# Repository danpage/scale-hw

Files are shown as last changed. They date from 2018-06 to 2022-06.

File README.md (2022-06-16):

# [SCALE](http://www.github.com/danpage/scale): hardware-oriented material

<!--- -------------------------------------------------------------------- --->

## Concept

The equipment used for a typical 
[side-channel attack](http://en.wikipedia.org/wiki/Side-channel_attack)
based on
[power analysis](http://en.wikipedia.org/wiki/Power_analysis)
might resemble the following:

```
                                                                   .... +-------------+
                                                                  /     | SCALE       |
+-------------+         +-------------+   trigger  +-------------+      | target      |
| control     |   USB   | acquisition | <--------- | target      |      | board       |
| platform    | <-----> | platform    |   signal   | platform    |      +-------------+
|             |         |             | <--------- |             |      | SCALE       |
+-------------+         +-------------+            +-------------+      | host        |
      ^                                                  ^        \     | board       |   
      |           USB                                    |         .... +-------------+
      +--------------------------------------------------+
```

The basic idea is that

- the target      platform represents the device under attack,
  or the
  [Device Under Test (DUT)](http://en.wikipedia.org/wiki/Device_under_test)
  in more common terms,

- the acquisition platform represents a   device, e.g., an
  [oscilloscope](http://en.wikipedia.org/wiki/Oscilloscope),
  to capture a signal from the target platform (under control of a trigger)
  and relay it to the control platform,

- the control     platform represents a workstation, which orchestrates the 
  attack by controlling the target and acquisition platforms: it will often
  repeat an acquisition loop, i.e.,

  - configure (e.g., fix the acquisition period) and initialise (e.g., arm 
    the trigger) the acquisition platform,
  - send    input     (e.g.,  plaintext) to   target      platform,
  - invoke  operation (e.g., encryption) on   target      platform,
  - receive output    (e.g., ciphertext) from target      platform,
    then,
  - receive trace                        from acquisition platform,

  to acquire a set of traces, then apply some 
  [(crypt)analytic](http://en.wikipedia.org/wiki/Cryptanalysis) 
  technique to them in order to recover information.

None of the above is an unreasonable expectation within the context of a 
research-oriented lab. but may present challenges in a teaching-oriented
alternative.  For example, particularly at scale, it may be that

- the 
  [Total Cost of Ownership (TCO)](http://en.wikipedia.org/wiki/Total_cost_of_ownership),
  i.e., capital investment plus maintenance, 
- the domain-specific requirements on 
  [Commercial Off-The-Shelf (COTS)](http://en.wikipedia.org/wiki/Commercial_off-the-shelf)
  target boards, such as the need to insert a shunt resistor into the 
  power rail,
- the need to expose at least some
  [EE](http://en.wikipedia.org/wiki/Electrical_engineering)-style 
  detail to students without a suitable background,

prevent such an approach being viable (or make it less effective).

This repo. captures a suite of 
bespoke, hardware-based target platform designs:
when combined with suitable control and acquisition platforms, it offers
a real, albeit sanitised "kit" for learning about side-channel attacks.
It has a strict remit, namely educational use (e.g., as a lab. exercise 
or assignment), which to some extent determines goals, design decisions, 
and, ultimately, the content.

<!--- -------------------------------------------------------------------- --->

## Quickstart

- Install any pre-requisites, e.g., support for
  [Git Large File Storage (LFS)](http://git-lfs.github.com/)
  (without this, some content will appear as a set of pointers to data vs. the data itself).

- Clone the repo.

  ```sh
  git clone https://github.com/danpage/scale-hw.git ./scale-hw
  cd ./scale-hw
  git submodule update --init --recursive
  source ./bin/conf.sh
  ```

- Create and populate a suitable Python
  [virtual environment](https://docs.python.org/3/library/venv.html)
  based on 
  [`${REPO_HOME}/requirements.txt`](./requirements.txt) 
  by executing
   
  ```sh
  make venv
  ```
   
  then activate it by executing
   
  ```sh
  source ${REPO_HOME}/build/venv/bin/activate
  ``` 

- Select a target board, e.g., by setting the environment variable

  ```sh
  export TARGET="lpc1313fbd48"
  ```

- Build the material 
  by executing

  ```sh
  make --directory="${REPO_HOME}/src/scale/target/${TARGET}" build
  ```

- Make use of the material in

  ```sh
  ${REPO_HOME}/build/${TARGET}
  ```

  e.g.,

  - build   the example:

    ```sh
    make --directory="${REPO_HOME}/src/scale/example" --file="${REPO_HOME}/build/${TARGET}/lib/scale.mk" PROJECT="example" BSP="${REPO_HOME}/build/${TARGET}" USB="/dev/ttyUSB0" build
    ```

  - program the example (i.e., execute it on physical hardware):

    ```sh
    make --directory="${REPO_HOME}/src/scale/example" --file="${REPO_HOME}/build/${TARGET}/lib/scale.mk" PROJECT="example" BSP="${REPO_HOME}/build/${TARGET}" USB="/dev/ttyUSB0" program
    ```

  - emulate the example (i.e., execute it on  virtual hardware):

    ```sh
    make --directory="${REPO_HOME}/src/scale/example" --file="${REPO_HOME}/build/${TARGET}/lib/scale.mk" PROJECT="example" BSP="${REPO_HOME}/build/${TARGET}" USB="/dev/ttyUSB0" emulate
    ```

<!--- -------------------------------------------------------------------- --->

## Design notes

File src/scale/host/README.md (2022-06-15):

# [SCALE](http://www.github.com/danpage/scale): hardware-oriented material (host board)

<!--- -------------------------------------------------------------------- --->

## Hardware 

Revision | Prototype                                                                                                 | PCB                                                                                           | Design files                                                                                                                                                                                                                 |
:------: | :-------------------------------------------------------------------------------------------------------: | :-------------------------------------------------------------------------------------------: | :--------------------------------------------------------------------------------------------------------------------------------------------------------------------------------------------------------------------------: |
C.1      |  |  | [schematic](./board.sch) (plus [PDF](./board.pdf)), [board](./board.brd), [BOM](./board.csv), [OSH Park (PCB)](http://www.oshpark.com/shared_projects/F13RPtpf), [Octopart (BOM)](http://www.octopart.com/bom-tool/LBFQutEU) |

- All communication with a control platform is performed via a
  [USB](http://en.wikipedia.org/wiki/USB)-to-[UART](http://en.wikipedia.org/wiki/Universal_asynchronous_receiver/transmitter)
  bridge, namely an
  [FTDI FT232RL](http://www.ftdichip.com/Support/Documents/DataSheets/ICs/DS_FT232R.pdf)
  (which ultimately connects to `DUT_RXD` and `DUT_TXD`).
  The surrounding design

  - basically matches the
    [SparkFun FTDI Basic Breakout](http://cdn.sparkfun.com/datasheets/BreakoutBoards/FTDI%20Basic-v22-3.3V.pdf),
    but includes a polyfuse (the breadboard prototype seems to pull about
    30 mA @ 3.3V),

  - differs from Figure 7.4 (page 31) of FT232RL datasheet wrt. both the 
    capacitors, and lack of ferrite bead.

- Both `DUT_RST` and `DUT_GPI` are connected to
  [SPST switches](http://en.wikipedia.org/wiki/Switch)
  switches.
  The surrounding design is motivated by 
  [Arduino UNO](http://www.arduino.cc/en/uploads/Main/arduino-uno-schematic.pdf),
  replacing `GND` with `UART_DTR` on the non-switch side of the capacitor
  to allow a programmer, e.g., `avrdude`, to perform a "remote reset".

- The center pin of `H.J2` ultimately supplies power the target board via 
  `DUT_VCC`: a jumper can be used to select between

  - a   5 V supply stemming from the FT232RL,
    or
  - a 3.3 V supply stemming from the FT232RL,

  or, by default (i.e., with no jumper), an external power supply which
  is provided via the labelled SMA connector and hence `PSU`.

- A signal is acquired from either `DUT_VCC` or `DUT_SIGI`, depending on
  `H.J4`, before being processed by a pipeline of components and produced
  via `DUT_SIGO`.

  - The pipeline includes a 
    100 ohm shunt resistor,
    which can be enabled or disabled using `H.J3`.

  - The pipeline includes a
    [Low Noise Amplifier (LNA)](http://en.wikipedia.org/wiki/Low-noise_amplifier),
    namely an
    [NXP BGA2801](http://www.nxp.com/documents/data_sheet/BGA2801.pdf),
    which can be enabled or disabled using `H.J5`.
    The surrounding design is basically the same as the
    [ChipWhisperer LNA module](http://wiki.newae.com/CW502_Low_Noise_Amplifier),
    which, in turn, is basically the same as the NXP reference design in
    Figure 1 (page 4) of the BGA2801 datasheet.
  
  - The pipeline includes a
    [low-pass filter](http://en.wikipedia.org/wiki/Low-pass_filter);
    which can be enabled or disabled using `H.J6`.
    The surrounding design is based in a "pi-section" structure, i.e.,
  
    ```
                 L
      ----o---8888888---o----
          |             |
          = C/2         = C/2
          |             |
         GND           GND
    ```
  
    where we select
    L   =  10.0 uH
    and
    C/2 =   1.5 nF
    to produce roughly a 2.6 MHz cut-off.

- `DUT_SCL` and `DUT_SDA` are connected to three
  [Atmel CryptoAuthentication](http://www.atmel.com/products/security-ics/cryptoauthentication)
  I2C peripherals, 
  which can be enabled or disabled using `H.J7`.
  More specifically, those peripherals are one each of

  - [ATAES132A](http://www.atmel.com/Images/Atmel-8914-CryptoAuth-ATAES132A-Datasheet.pdf),
  - [ATSHA204A](http://www.atmel.com/images/Atmel-8885-CryptoAuth-ATSHA204A-Datasheet.pdf),
    and
  - [ATECC508A](http://www.atmel.com/Images/Atmel-8923S-CryptoAuth-ATECC508A-Datasheet-Summary.pdf),

  that offer hardware-backed, cryptography-related functionality and
  some amount of generic 
  [EEPROM](http://en.wikipedia.org/wiki/EEPROM)
  storage.

<!--- -------------------------------------------------------------------- --->

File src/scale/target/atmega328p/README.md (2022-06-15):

# [SCALE](http://www.github.com/danpage/scale): hardware-oriented material (target board: atmega328p)

<!--- -------------------------------------------------------------------- --->

## Hardware 

Revision | Prototype                                                                                                 | PCB                                                                                           | Design files                                                                                                                                                                                                                 |
:------: | :-------------------------------------------------------------------------------------------------------: | :-------------------------------------------------------------------------------------------: | :--------------------------------------------------------------------------------------------------------------------------------------------------------------------------------------------------------------------------: |
C.1      |  |  | [schematic](./board.sch) (plus [PDF](./board.pdf)), [board](./board.brd), [BOM](./board.csv), [OSH Park (PCB)](http://www.oshpark.com/shared_projects/YczSc1Wc), [Octopart (BOM)](http://www.octopart.com/bom-tool/CbDjCRPB) |

- The target board houses an 
  8-bit Atmel ATmega
  core, which acts as the 
  [DUT](http://en.wikipedia.org/wiki/Device_under_test).
  More specifically, the DUT is a
  28-pin, DIP-format
  [Atmel atmega328p](http://www.atmel.com/Images/Atmel-42735-8-bit-AVR-Microcontroller-ATmega328-328P_Datasheet.pdf)
  IC; 
  it has 32 kB FLASH and 2 kB SRAM memory.

- Relevant aspects of the DUT pin-out, and their relationship with the
  target board schematic, are illustrated below:

  ```
                       +------------+
  DUT_RST   = PC6  =  1|            |28 =         DUT_SCL
  DUT_RXD   = PD0  =  2|            |27 =         DUT_SDA
  DUT_TXD   = PD1  =  3|            |26
  DUT_GPI   = PD2  =  4|            |25
                      5|            |24
                      6|            |23
  DUT_VCC   = VCC  =  7| ATmega328p |22 =  GND
              GND  =  8|            |21
  DUT_XTAL1 = PB6  =  9|            |20 =  VCC  = DUT_VCC
  DUT_XTAL2 = PB7  = 10|            |19 =  SCK
                     11|            |18 =  MISO
                     12|            |17 =  MOSI
  DUT_GPO   = PD7  = 13|            |16
  DUT_TGR   = PB0  = 14|            |15
                       +------------+
  ```

- The core voltage required on `DUT_VCC` is 5 V: 
  `H.J2` must therefore be set appropriately.

- The core has a
  1 MHz
  internal clock source, but can be driven by either 

  - an external clock source provided (on `DUT_XTAL1` and `DUT_XTAL2` via `DUT_CLK`),
    or
  - 16 MHz external crystal housed on the target board.

  To support these, some extra, carefully selected capacitors
  are required: the DUT
  [datasheet](http://www.atmel.com/Images/Atmel-42735-8-bit-AVR-Microcontroller-ATmega328-328P_Datasheet.pdf)
  specifies that

  | Type    | Reference   | XTALIN  (`DUT_XTAL1`)                                  | XTALOUT (`DUT_XTAL2`)   |
  |:-------:|:-----------:|:------------------------------------------------------:|:-----------------------:|
  | Crystal | Figure 13-2 | C1   =  22 pF = 0.022 nF                               | C2   = 22 pF = 0.022 nF |
  | Clock   | Figure 13-3 | no capacitors required                                 | disconnected            |

- Specific pins on the DUT are made accessible via `T.J2` in order to
  allow attachment of a hardware programmer or debugger.
  For example, it is possible to attach an
  [Atmel AVRISP mkII](http://www.atmel.com/Images/Atmel-42093-AVR-ISP-mkII_UserGuide.pdf)
  (or indeed *any* low-cost ISP-based programmer)
  to the DUT by connecting the 6-pin header as follows

  ```
             +-----+
     MISO = 1|     |2 = DUT_VCC
      SCK = 3| ISP |4 = MOSI
  DUT_RST = 5|     |6 = DUT_GND
             +-----+
  ```

  taking care wrt. pin 2.  Some programmers will sense a core voltage
  from this pin, some will *supply* a core voltage using it, some can
  be configured to do either: by whatever means (e.g., disconnecting
  the pin, or configuring the programmer), do *not* use it supply a 
  core voltage.

<!--- -------------------------------------------------------------------- --->

## Software

- Under
  [Ubuntu](http://www.ubuntu.com)-based
  Linux, for example, 
  the development dependencies can be installed 
  by issuing the command

  ```
  sudo apt-get install gcc-avr avrdude
  ```

- We assume an Arduino-based
  [bootloader](http://en.wikipedia.org/wiki/Booting),
  such as
  [Optiboot](http://www.github.com/Optiboot/optiboot),
  has been pre-installed to allow programming of the DUT over USB;
  this means
  [avrdude](http://www.nongnu.org/avrdude)
  can be used as is,
  as can the Arduino
  [IDE](http://www.arduino.cc/en/main/software)
  if you prefer.

- Note that the default BSP configuration is conservative, st.

  - the
    external 16 MHz crystal
    is used as the clock source,
    meaning `T.J3` and `T.J4` on the target board 
    must be set appropriately,
  - the 
    UART 
    interface operates per 9600/8N1,
  - the
    I2C
    interface operates per 100 kHz standard mode.

<!--- -------------------------------------------------------------------- --->

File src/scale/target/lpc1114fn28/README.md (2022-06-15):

# [SCALE](http://www.github.com/danpage/scale): hardware-oriented material (target board: lpc1114fn28)

<!--- -------------------------------------------------------------------- --->

## Hardware 

Revision | Prototype                                                                                                 | PCB                                                                                           | Design files                                                                                                                                                                                                                 |
:------: | :-------------------------------------------------------------------------------------------------------: | :-------------------------------------------------------------------------------------------: | :--------------------------------------------------------------------------------------------------------------------------------------------------------------------------------------------------------------------------: |
C.1      |  |  | [schematic](./board.sch) (plus [PDF](./board.pdf)), [board](./board.brd), [BOM](./board.csv), [OSH Park (PCB)](http://www.oshpark.com/shared_projects/XgebkWyr), [Octopart (BOM)](http://www.octopart.com/bom-tool/vM74sniH) |

- The target board houses a
  32-bit ARM Cortex-M0 
  core, which acts as the 
  [DUT](http://en.wikipedia.org/wiki/Device_under_test).
  More specifically, the DUT is a
  28-pin, DIP-format
  [NXP lpc114fn28/102](http://www.nxp.com/documents/data_sheet/LPC111X.pdf)
  IC (the
  [user manual](http://www.nxp.com/documents/user_manual/UM10398.pdf)
  for which is more detailed); 
  it has 32 kB FLASH and 4 kB SRAM memory.
  Unfortunately NXP have discontinued this part, although you can often
  still source instances via
  [ebay](http://www.ebay.co.uk/sch/lpc114fn28).

- Relevant aspects of the DUT pin-out, and their relationship with the
  target board schematic, are illustrated below:

  ```
                       +----------------+
  DUT_TRG = PIO0_8 =  1|                |28
  DUT_GPO = PIO0_9 =  2|                |27           = DUT_SCL            
            SWCLK  =  3|                |26             
                      4|                |25             
  DUT_SDA =           5|                |24 = PIO0_1  = DUT_GPI
                      6|                |23           = DUT_RST       
                      7| lpc114fn28/102 |22 = GND     = DUT_GND
                      8|                |21 = VCC     = DUT_VCC
                      9|                |20 = XTALIN  = DUT_XTAL1
                     10|                |19 = XTALOUT = DUT_XTAL2
                     11|                |18             
            SWDIO  = 12|                |17             
                     13|                |16           = DUT_TXD       
                     14|                |15           = DUT_RXD
                       +----------------+
  ```

- The core voltage required on `DUT_VCC` is 3.3 V: 
  `H.J2` must therefore be set appropriately.

- The core has a
  12 MHz
  internal oscillator, but can be driven by either 

  - an external clock source provided (on `DUT_XTAL1` and `DUT_XTAL2` via `DUT_CLK`),
    or
  - 16 MHz external crystal housed on the target board.

  To support these, some extra, carefully selected capacitors
  are required: the DUT
  [datasheet](http://www.nxp.com/documents/data_sheet/LPC111X.pdf)
  specifies that for C_L = 10 pF crystal load capacitance,

  | Type    | Reference             | XTALIN  (`DUT_XTAL1`)                                  | XTALOUT (`DUT_XTAL2`)   |
  |:-------:|:---------------------:|:------------------------------------------------------:|:-----------------------:|
  | Crystal | Figure 50, Table  30  | C_X1 =  18 pF = 0.018 nF                               | C_X2 = 18 pF = 0.018 nF |
  | Clock   | Figure 49             | C_i  = 100 pF = 0.100 nF <br/> C_g = 300 pF = 0.300 nF | disconnected            |

  In the latter case we want 200 mV < f * V_RMS < 1000 mV, where
  f = C_i / ( C_i + C_g ),
  so if we pick V_peak = 3.3 V, then because
  V_RMS  = V_peak * \sqrt{duty cycle}
         = 3.3    * \sqrt{1/2}
        ~= 2.3
  then f = 1/4 and hence C_g = 300 pF does the job.

- Specific pins on the DUT are made accessible via `T.J2` in order to
  allow attachment of a hardware programmer or debugger.
  For example, it is possible to attach a
  [Segger J-Link](http://www.segger.com/admin/uploads/productDocs/UM08001_JLink.pdf)
  to the DUT by connecting the 20-pin header as follows

  ```
              +--------+
  DUT_VCC =  1|        |2
             3|        |4  = DUT_GND
             5|        |6
    SWDIO =  7|        |8
    SWCLK =  9| J-Link |10
            11|        |12
            13|        |14
  DUT_RST = 15|        |16
            17|        |18
            19|        |20
              +--------+
  ```
               
  and thereby make use of Serial Wire Debug (SWD).

<!--- -------------------------------------------------------------------- --->

## Software

- Under
  [Ubuntu](http://www.ubuntu.com)-based
  Linux, for example, 
  the development dependencies can be installed 
  by issuing the command

  ```
  sudo apt-get install gcc-arm-none-eabi lpc21isp
  ```

  That said, some versions of this 
  [Ubuntu packaged](https://launchpad.net/ubuntu/+source/gcc-arm-none-eabi) 
  tool-chain have known issues 
  (see, e.g., [1](https://bugs.launchpad.net/gcc-arm-embedded/+bug/1722849)
              or
              [2](https://bugs.launchpad.net/gcc-arm-embedded/+bug/1502611));
  take care, or, as an alternative, consider using an 
  ["official" release](https://developer.arm.com/tools-and-software/open-source-software/developer-tools/gnu-toolchain)
  directly from ARM instead.

- A pre-installed 
  [bootloader](http://en.wikipedia.org/wiki/Booting)
  allows programming of the DUT over USB;
  this means
  [lpc21isp](http://sourceforge.net/projects/lpc21isp)
  can be used as is.  
  The GPI switch on the host board will activate the bootloader during 
  reset, so the steps required are basically

  - execute lpc2isp, which then waits,
  - press and hold the (right-hand) GPI   switch,  
  - press and hold the  (left-hand) reset switch,
  - release        the  (left-hand) reset switch,
  - transfer via lpc2isp starts,
  - release        the (right-hand) GPI   switch,
  - transfer via lpc2isp finishes.

- Note that the default BSP configuration is conservative, st.

  - the
    internal 12 MHz oscillator
    is used as the clock source,
    meaning `T.J3` and `T.J4` on the target board 
    are irrelevant,
  - the 
    UART 
    interface operates per 9600/8N1,
  - the
    I2C
    interface operates per 100 kHz standard mode.

<!--- -------------------------------------------------------------------- --->

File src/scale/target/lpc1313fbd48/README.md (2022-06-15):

# [SCALE](http://www.github.com/danpage/scale): hardware-oriented material (target board: lpc1313fbd48)

<!--- -------------------------------------------------------------------- --->

## Hardware 

Revision | Prototype                                                                                                 | PCB                                                                                           | Design files                                                                                                                                                                                                                 |
:------: | :-------------------------------------------------------------------------------------------------------: | :-------------------------------------------------------------------------------------------: | :--------------------------------------------------------------------------------------------------------------------------------------------------------------------------------------------------------------------------: |
C.1      |  |  | [schematic](./board.sch) (plus [PDF](./board.pdf)), [board](./board.brd), [BOM](./board.csv), [OSH Park (PCB)](http://www.oshpark.com/shared_projects/dp9i0DIr), [Octopart (BOM)](http://www.octopart.com/bom-tool/5ZnEZk9y) |

- The target board houses a
  32-bit ARM Cortex-M3
  core, which acts as the 
  [DUT](http://en.wikipedia.org/wiki/Device_under_test).
  More specifically, the DUT is a
  48-pin, LQFP-format
  [NXP lpc1313fbd48/151](http://www.nxp.com/docs/en/data-sheet/LPC1311_13_42_43.pdf)
  IC (the
  [user manual](http://www.nxp.com/docs/en/user-guide/UM10375.pdf)
  for which is more detailed); 
  it has 32 kB FLASH and 8 kB SRAM memory.

- Relevant aspects of the DUT pin-out, and their relationship with the
  target board schematic, are illustrated below:

  ```
                             +----------------------- = TXD    = DUT_TXD
                             | +--------------------- = RXD    = DUT_RXD
                             | |   +----------------- = VDD    = DUT_VCC
                             | |   |     +----------- = VSS    = DUT_GND
                             | |   |     |   +------- = SWDIO
                             | |   |     |   |
                                           
                           4 4 4 4 4 4 4 4 4 3 3 3
                           8 7 6 5 4 3 2 1 0 9 8 7
                          +-----------------------+
                         1|                       |36
                         2|                       |35 
  DUT_RST             =  3|                       |34 = PIO1_1 = DUT_GPO
  DUT_GPI   = PIO0_1  =  4|                       |33 = PIO1_0 = DUT_TRG
  DUT_GND   = VSS     =  5|                       |32
  DUT_XTAL1 = XTALIN  =  6|      lpc1313fbd48     |31
  DUT_XTAL2 = XTALOUT =  7|                       |30
  DUT_VCC   = VDD     =  8|                       |29 = SWCLK
                         9|                       |28 = SWO
                        10|                       |27
                        11|                       |26
                        12|                       |25
                          +-----------------------+
                           1 1 1 1 1 1 1 2 2 2 2 2
                           3 4 5 6 7 8 9 0 1 2 3 4

                               | |
  DUT_SCL   = SCL     = -------+ |
  DUT_SDA   = SDA     = ---------+
  ```

- The core voltage required on `DUT_VCC` is 3.3 V: 
  `H.J2` must therefore be set appropriately.

- The core has a
  12 MHz
  internal oscillator, but can be driven by either 

  - an external clock source provided (on `DUT_XTAL1` and `DUT_XTAL2` via `DUT_CLK`),
    or
  - 16 MHz external crystal housed on the target board.

  To support these, some extra, carefully selected capacitors
  are required: the DUT
  [datasheet](http://www.nxp.com/docs/en/data-sheet/LPC1311_13_42_43.pdf)
  specifies that for C_L = 10 pF crystal load capacitance,

  | Type    | Reference             | XTALIN  (`DUT_XTAL1`)                                  | XTALOUT (`DUT_XTAL2`)   |
  |:-------:|:---------------------:|:------------------------------------------------------:|:-----------------------:|
  | Crystal | Figure 35, Table  21  | C_X1 =  18 pF = 0.018 nF                               | C_X2 = 18 pF = 0.018 nF |
  | Clock   | Figure 34             | C_i  = 100 pF = 0.100 nF <br/> C_g = 300 pF = 0.300 nF | disconnected            |

  In the latter case we want 200 mV < f * V_RMS < 1000 mV, where
  f = C_i / ( C_i + C_g ),
  so if we pick V_peak = 3.3 V, then because
  V_RMS  = V_peak * \sqrt{duty cycle}
         = 3.3    * \sqrt{1/2}
        ~= 2.3
  then f = 1/4 and hence C_g = 300 pF does the job.

- Specific pins on the DUT are made accessible via `T.J2` in order to
  allow attachment of a hardware programmer or debugger.
  For example, it is possible to attach a
  [Segger J-Link](http://www.segger.com/admin/uploads/productDocs/UM08001_JLink.pdf)
  to the DUT by connecting the 20-pin header as follows

  ```
              +--------+
  DUT_VCC =  1|        |2
             3|        |4  = DUT_GND
             5|        |6
    SWDIO =  7|        |8
    SWCLK =  9| J-Link |10
            11|        |12
            13|        |14
  DUT_RST = 15|        |16
            17|        |18
            19|        |20
              +--------+
  ```
               
  and thereby make use of Serial Wire Debug (SWD).

  That said, it *seems* the DUT isn't correctly identified by 
  [OpenOCD](http://openocd.org),
  at least per version 
  [0.10.0](http://sourceforge.net/p/openocd/code/ci/v0.10.0/tree/).  
  It's not totally clear why: the flash driver seems to read a part ID
  of `0x2000002B` (vs. an expected part ID `0x2C40102B`).  This can be 
  resolved by adding something like

  ```
  #define LPC1313_2 0x2000002B
  ```
 
  plus an appropriate case in the `lpc2000_auto_probe_flash` function 
  of
  [`${OPENOCD}/src/flash/nor/lpc2000.c`](http://sourceforge.net/p/openocd/code/ci/v0.10.0/tree/src/flash/nor/lpc2000.c);
  alternatively, apply the
  [patch](./openocd-0.10.0.patch)
  provided.

<!--- -------------------------------------------------------------------- --->

## Software

- Under
  [Ubuntu](http://www.ubuntu.com)-based
  Linux, for example, 
  the development dependencies can be installed 
  by issuing the command

  ```
  sudo apt-get install gcc-arm-none-eabi lpc21isp
  ```

  That said, some versions of this 
  [Ubuntu packaged](https://launchpad.net/ubuntu/+source/gcc-arm-none-eabi) 
  tool-chain have known issues 
  (see, e.g., [1](https://bugs.launchpad.net/gcc-arm-embedded/+bug/1722849)
              or
              [2](https://bugs.launchpad.net/gcc-arm-embedded/+bug/1502611)):
  take care, or, as an alternative, consider using an 
  ["official" release](https://developer.arm.com/tools-and-software/open-source-software/developer-tools/gnu-toolchain)
  directly from ARM instead.

- A pre-installed 
  [bootloader](http://en.wikipedia.org/wiki/Booting)
  allows programming of the DUT over USB;
  this means
  [lpc21isp](http://sourceforge.net/projects/lpc21isp)
  can be used as is.  
  The GPI switch on the host board will activate the bootloader during 
  reset, so the steps required are basically

  - execute lpc2isp, which then waits,
  - press and hold the (right-hand) GPI   switch,  
  - press and hold the  (left-hand) reset switch,
  - release        the  (left-hand) reset switch,
  - transfer via lpc2isp starts,
  - release        the (right-hand) GPI   switch,
  - transfer via lpc2isp finishes.

- Note that the default BSP configuration is conservative, st.

  - the
    internal 12 MHz oscillator
    is used as the clock source,
    meaning `T.J3` and `T.J4` on the target board 
    are irrelevant,
  - the 
    UART 
    interface operates per 9600/8N1,
  - the
    I2C
    interface operates per 100 kHz standard mode.

<!--- -------------------------------------------------------------------- --->

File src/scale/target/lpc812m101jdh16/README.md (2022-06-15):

# [SCALE](http://www.github.com/danpage/scale): hardware-oriented material (target board: lpc812m101jdh16)

<!--- -------------------------------------------------------------------- --->

## Hardware 

Revision | Prototype                                                                                                 | PCB                                                                                           | Design files                                                                                                                                                                                                                 |
:------: | :-------------------------------------------------------------------------------------------------------: | :-------------------------------------------------------------------------------------------: | :--------------------------------------------------------------------------------------------------------------------------------------------------------------------------------------------------------------------------: |
C.1      |  |  | [schematic](./board.sch) (plus [PDF](./board.pdf)), [board](./board.brd), [BOM](./board.csv), [OSH Park (PCB)](http://www.oshpark.com/shared_projects/ANKAjSGc), [Octopart (BOM)](http://www.octopart.com/bom-tool/BlsVKS9M) |

- The target board houses a
  32-bit ARM Cortex-M0+
  core, which acts as the 
  [DUT](http://en.wikipedia.org/wiki/Device_under_test).
  More specifically, the DUT is a
  16-pin, TSSOP-format
  [NXP lpc812m101jdh16](http://www.nxp.com/documents/data_sheet/LPC81XM.pdf)
  IC (the
  [user manual](http://www.nxp.com/documents/user_manual/UM10601.pdf)
  for which is more detailed); 
  it has 16 kB FLASH and 4 kB SRAM memory.

- Relevant aspects of the DUT pin-out, and their relationship with the
  target board schematic, are illustrated below:

  ```
                        +-----------------+
                       1|                 |16 = PIO0_0  = DUT_RXD
  DUT_GPI = PIO0_12 =  2|                 |15 = PIO0_6  = DUT_TRG
  DUT_RST =            3|                 |14 = PIO_7   = DUT_GPO
  DUT_TXD = PIO0_4  =  4| lpc812m101jdh16 |13 = GND     = DUT_GND
            SWCLK   =  5|                 |12 = VCC     = DUT_VCC
            SWDIO   =  6|                 |11 = XTALIN  = DUT_XTAL1
  DUT_SCL =            7|                 |10 = XTALOUT = DUT_XTAL2
  DUT_SDA =            8|                 |9 
                        +-----------------+
  ```

- The core voltage required on `DUT_VCC` is 3.3 V: 
  `H.J2` must therefore be set appropriately.

- The core has a
  12 MHz
  internal oscillator, but can be driven by either 

  - an external clock source provided (on `DUT_XTAL1` and `DUT_XTAL2` via `DUT_CLK`),
    or
  - 16 MHz external crystal housed on the target board.

  To support these, some extra, carefully selected capacitors
  are required: the DUT
  [datasheet](http://www.nxp.com/documents/data_sheet/LPC81XM.pdf)
  specifies that for C_L = 10 pF crystal load capacitance,

  | Type    | Reference             | XTALIN  (`DUT_XTAL1`)                                  | XTALOUT (`DUT_XTAL2`)   |
  |:-------:|:---------------------:|:------------------------------------------------------:|:-----------------------:|
  | Crystal | Figure 37, Table  26  | C_X1 =  18 pF = 0.018 nF                               | C_X2 = 18 pF = 0.018 nF |
  | Clock   | Figure 36             | C_i  = 100 pF = 0.100 nF <br/> C_g = 300 pF = 0.300 nF | disconnected            |

  In the latter case we want 200 mV < f * V_RMS < 1000 mV, where
  f = C_i / ( C_i + C_g ),
  so if we pick V_peak = 3.3 V, then because
  V_RMS  = V_peak * \sqrt{duty cycle}
         = 3.3    * \sqrt{1/2}
        ~= 2.3
  then f = 1/4 and hence C_g = 300 pF does the job.

- Specific pins on the DUT are made accessible via `T.J2` in order to
  allow attachment of a hardware programmer or debugger.
  For example, it is possible to attach a
  [Segger J-Link](http://www.segger.com/admin/uploads/productDocs/UM08001_JLink.pdf)
  to the DUT by connecting the 20-pin header as follows

  ```
              +--------+
  DUT_VCC =  1|        |2
             3|        |4  = DUT_GND
             5|        |6
    SWDIO =  7|        |8
    SWCLK =  9| J-Link |10
            11|        |12
            13|        |14
  DUT_RST = 15|        |16
            17|        |18
            19|        |20
              +--------+
  ```
               
  and thereby make use of Serial Wire Debug (SWD).

<!--- -------------------------------------------------------------------- --->

## Software

- Under
  [Ubuntu](http://www.ubuntu.com)-based
  Linux, for example, 
  the development dependencies can be installed 
  by issuing the command

  ```
  sudo apt-get install gcc-arm-none-eabi lpc21isp
  ```

  That said, some versions of this 
  [Ubuntu packaged](https://launchpad.net/ubuntu/+source/gcc-arm-none-eabi) 
  tool-chain have known issues 
  (see, e.g., [1](https://bugs.launchpad.net/gcc-arm-embedded/+bug/1722849)
              or
              [2](https://bugs.launchpad.net/gcc-arm-embedded/+bug/1502611));
  take care, or, as an alternative, consider using an 
  ["official" release](https://developer.arm.com/tools-and-software/open-source-software/developer-tools/gnu-toolchain)
  directly from ARM instead.

- A pre-installed 
  [bootloader](http://en.wikipedia.org/wiki/Booting)
  allows programming of the DUT over USB;
  this means
  [lpc21isp](http://sourceforge.net/projects/lpc21isp)
  can be used as is.  
  The GPI switch on the host board will activate the bootloader during 
  reset, so the steps required are basically

  - execute lpc2isp, which then waits,
  - press and hold the (right-hand) GPI   switch,  
  - press and hold the  (left-hand) reset switch,
  - release        the  (left-hand) reset switch,
  - transfer via lpc2isp starts,
  - release        the (right-hand) GPI   switch,
  - transfer via lpc2isp finishes.

- Note that the default BSP configuration is conservative, st.

  - the
    internal 12 MHz oscillator
    is used as the clock source,
    meaning `T.J3` and `T.J4` on the target board 
    are irrelevant,
  - the 
    UART 
    interface operates per 9600/8N1,
  - the
    I2C
    interface operates per 100 kHz standard mode.

<!--- -------------------------------------------------------------------- --->

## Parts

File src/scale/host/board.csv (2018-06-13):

Qty | Line Item | Manufacturer | Schematic Reference | Description
1 | FT232RL | FTDI | H.UART | USB to UART bridge; SSOP-28
1 | BGA2801,115 | NXP Semiconductors | H.AMP | wideband amplifier; SOT-363
1 | ATAES132A-SHER-B | Microchip | H.I2C1 | crypto. co-processor; SOIC-8
1 | ATSHA204A-SSHDA-B | Microchip | H.I2C2 | crypto. co-processor; SOIC-8
1 | ATECC108A-SSHDA-B | Microchip | H.I2C3 | crypto. co-processor; SOIC-8
2 | B3F-4000 | Omron | H.S1, H.S2 | SPST switch
1 | 61729-1011BLF | FCI | H.USB | USB receptacle
1 | 5-146281-2 | TE Connectivity | H.J7 | 2x1 male header
5 | 5-146281-3 | TE Connectivity | H.J2, H.J3, H.J4, H.J5, H.J6 | 3x1 male header
2 | 929974-01-16 | 3M | H.J1L, H.J1R | 16x1 female header
5 | 5-1814400-1 | TE Connectivity | H.X1, H.X2, H.X3, H.X4, H.X5 | horizontal female SMA connector
2 | APT3216SGC | Kingbright | H.D1, H.D2 | green LED; 1206
2 | APT3216YC | Kingbright | H.D3, H.D4 | yellow LED; 1206
1 | APT3216EC | Kingbright | H.D5 | red LED; 1206
1 | 1206L025YR | Littelfuse | H.F1 | 500 mA polyfuse; 1206
1 | MLZ1608N100LT000 | TDK | H.L1 | 10 uH inductor; 0603
1 | T491A106K010AT | KEMET | H.C3 | 10 uF tantalum capacitor; 1206
2 | C0603C152J8RACTU | KEMET | H.C10, H.C11 | 1.5 nF = 1500 pF ceramic capacitor; 0603
1 | C0603C223K1RACTU | KEMET | H.C8 | 22 nF = 0.022 uF ceramic capacitor; 0603
6 | C0603C104K8RACTU | KEMET | H.C1, H.C2, H.C4, H.C5, H.C6, H.C9 | 100 nF = 0.1 uF ceramic capacitor; 0603
1 | C0603C475K8PACTU | KEMET | H.C7 | 4.7 uF ceramic capacitor; 0603
1 | CR0603-JW-101ELF | Bourns | H.R8 | 100 ohm resistor; 0603
5 | CR0603-JW-102ELF | Bourns | H.R1, H.R2, H.R3, H.R4, H.R5 | 1k ohm resistor; 0603
2 | CR0603-JW-103ELF | Bourns | H.R6, H.R7 | 10k ohm resistor; 0603
2 | CR0603-JW-392ELF | Bourns | H.R9, H.R10 | 3.9k ohm resistor; 0603

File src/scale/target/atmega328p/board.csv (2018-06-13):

Qty | Line Item | Manufacturer | Schematic Reference | Description
1 | FOXSLF/160-20 | Fox Electronics | T.XTAL | 16 MHz crystal
1 | 952-2748-ND | Harwin | T.DUT | 28-pin DIP socket
1 | ATMEGA328P-PU | Microchip | T.DUT; DIP-28
2 | 5-146281-2 | TE Connectivity | T.J5, T.J6 | 2x1 male header
2 | 5-146281-3 | TE Connectivity | T.J3, T.J4 | 3x1 male header
1 | 5-146254-3 | TE Connectivity | T.J2 | 3x2 male header
2 | 961116-6404-AR | 3M | T.J1L, T.J1R | 16x1 male header
2 | C0603C220J5GACTU | KEMET | T.C1, T.C2 | 0.022 nF = 22 pF ceramic capacitor; 0603

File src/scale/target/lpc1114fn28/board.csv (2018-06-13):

Qty | Line Item | Manufacturer | Schematic Reference | Description
1 | FOXSLF/160-20 | Fox Electronics | T.XTAL | 16 MHz crystal
1 | 9-1437539-2 | TE Connectivity | T.DUT | 28-pin DIP socket
1 | LPC1114FN28/102,12 | NXP Semiconductors | T.DUT; DIP-28
2 | 5-146281-2 | TE Connectivity | T.J5, T.J6 | 2x1 male header
2 | 5-146281-3 | TE Connectivity | T.J3, T.J4 | 3x1 male header
1 | 4-103328-4 | TE Connectivity | T.J2 | 10x2 male header
2 | 961116-6404-AR | 3M | T.J1L, T.J1R | 16x1 male header
2 | C0603C180J5GACTU | KEMET | T.C1, T.C2 | 0.018 nF = 18 pF ceramic capacitor; 0603
1 | C0603C301J5GACTU | KEMET | T.C3 | 0.3 nF = 300 pF ceramic capacitor; 0603
1 | C0603C101J5GACTU | KEMET | T.C4 | 0.1 nF = 100 pF ceramic capacitor; 0603

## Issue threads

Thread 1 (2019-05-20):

lpc81x / M0+ builds not working - Typo in lpc81x.S

ben-marshall, 2019-05-20:
[Line 22](https://github.com/danpage/scale-hw/blob/fa15667bf32cdae6ed65c8f2c26735290ff85429/share/lpc81x/lpc81x.S#L22) of `/share/lpc81x/lpc81x.S` makes the wrong symbol name globally available.

It currently says `LPC81X_GPIO0`, but should say `LPC81X_GPIO` - i.e., there shouldn't be a trailing zero.

danpage, 2019-05-20:
Great: thanks.  I'm collecting a bunch of fixes in the `fixes` branch, so have addressed it there and will merge into `master` once I'm done with the rest.

Closed 2019-05-31.

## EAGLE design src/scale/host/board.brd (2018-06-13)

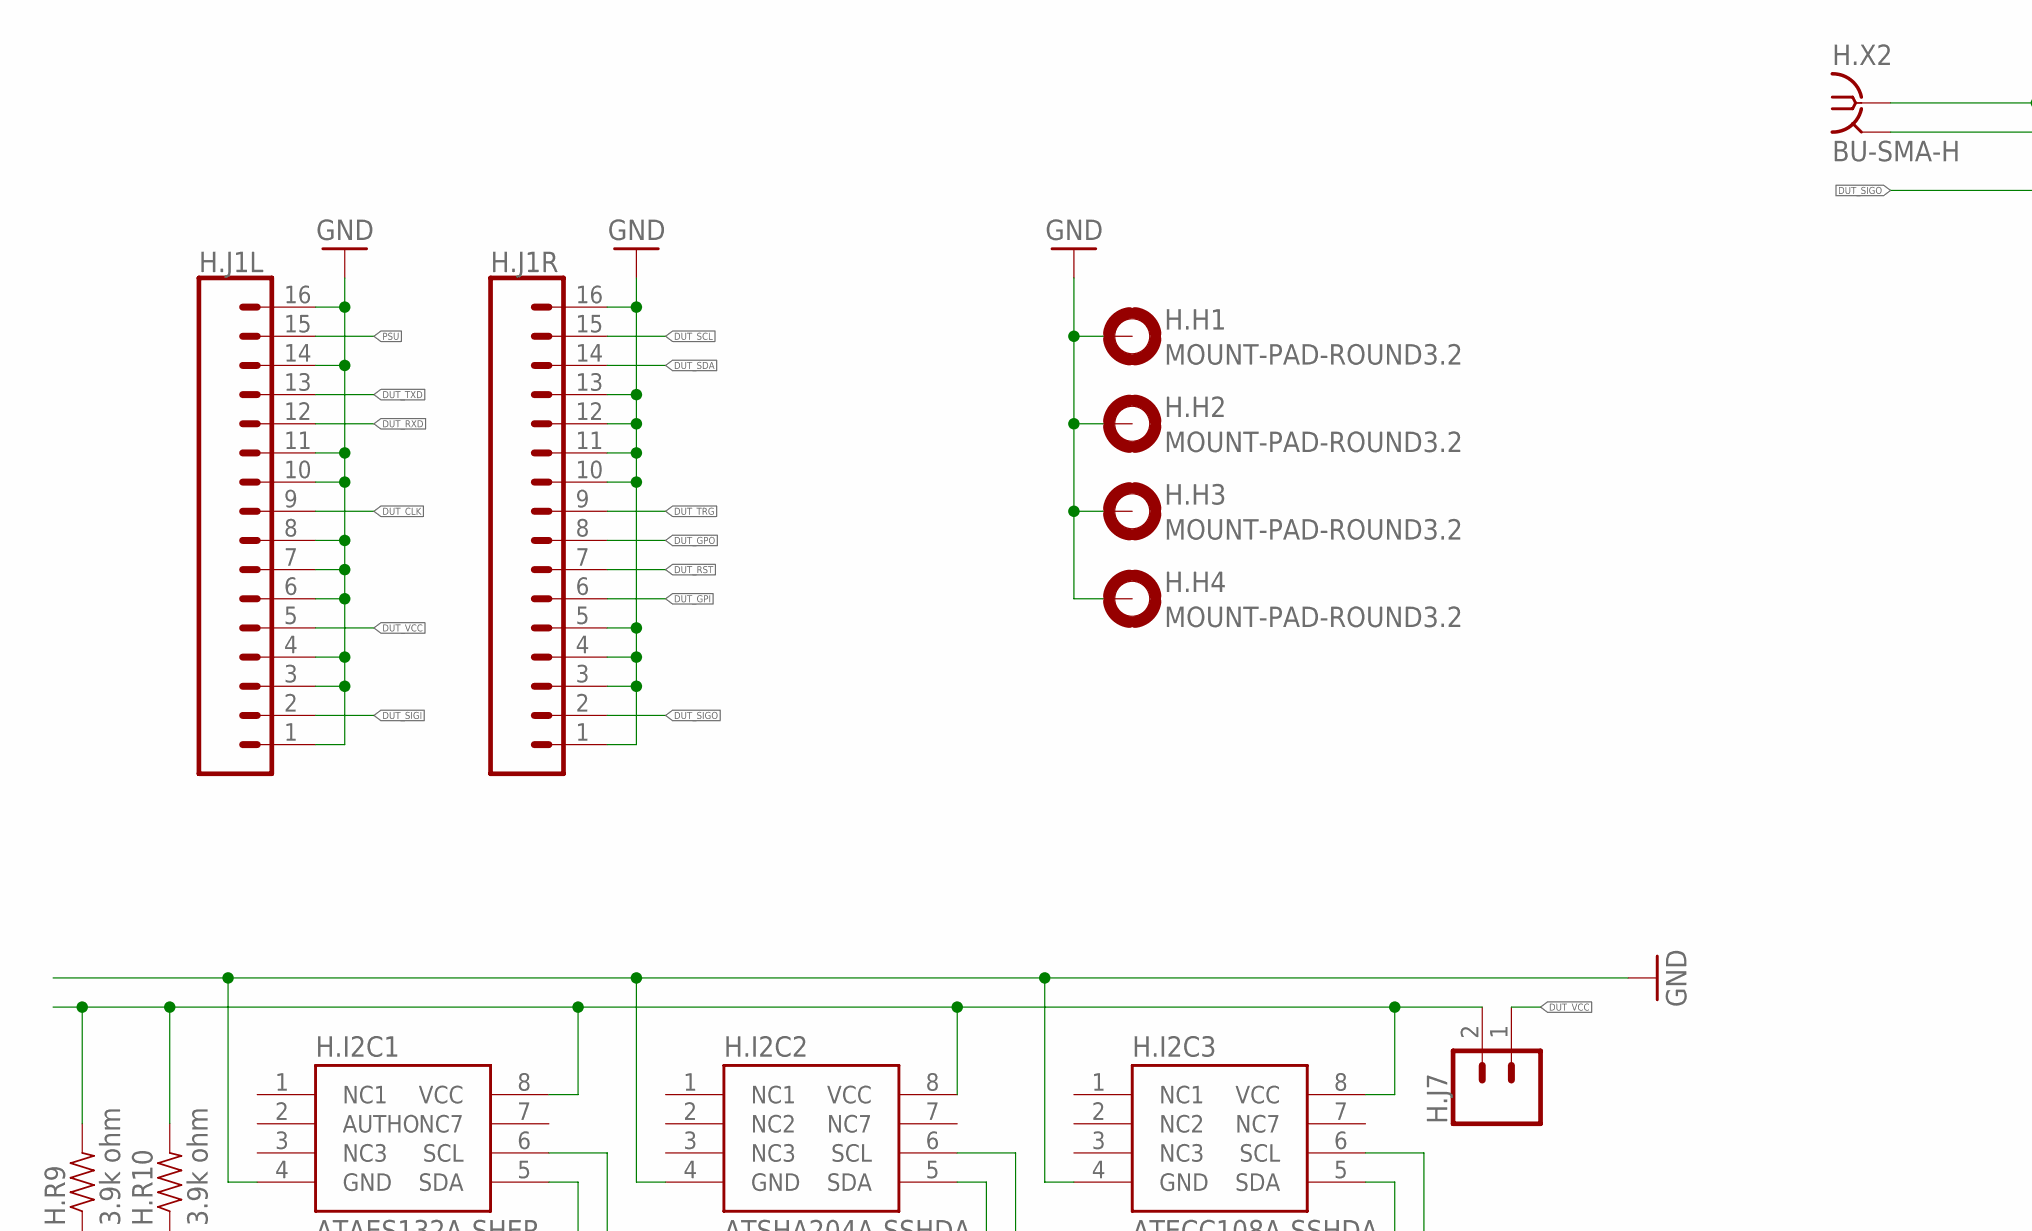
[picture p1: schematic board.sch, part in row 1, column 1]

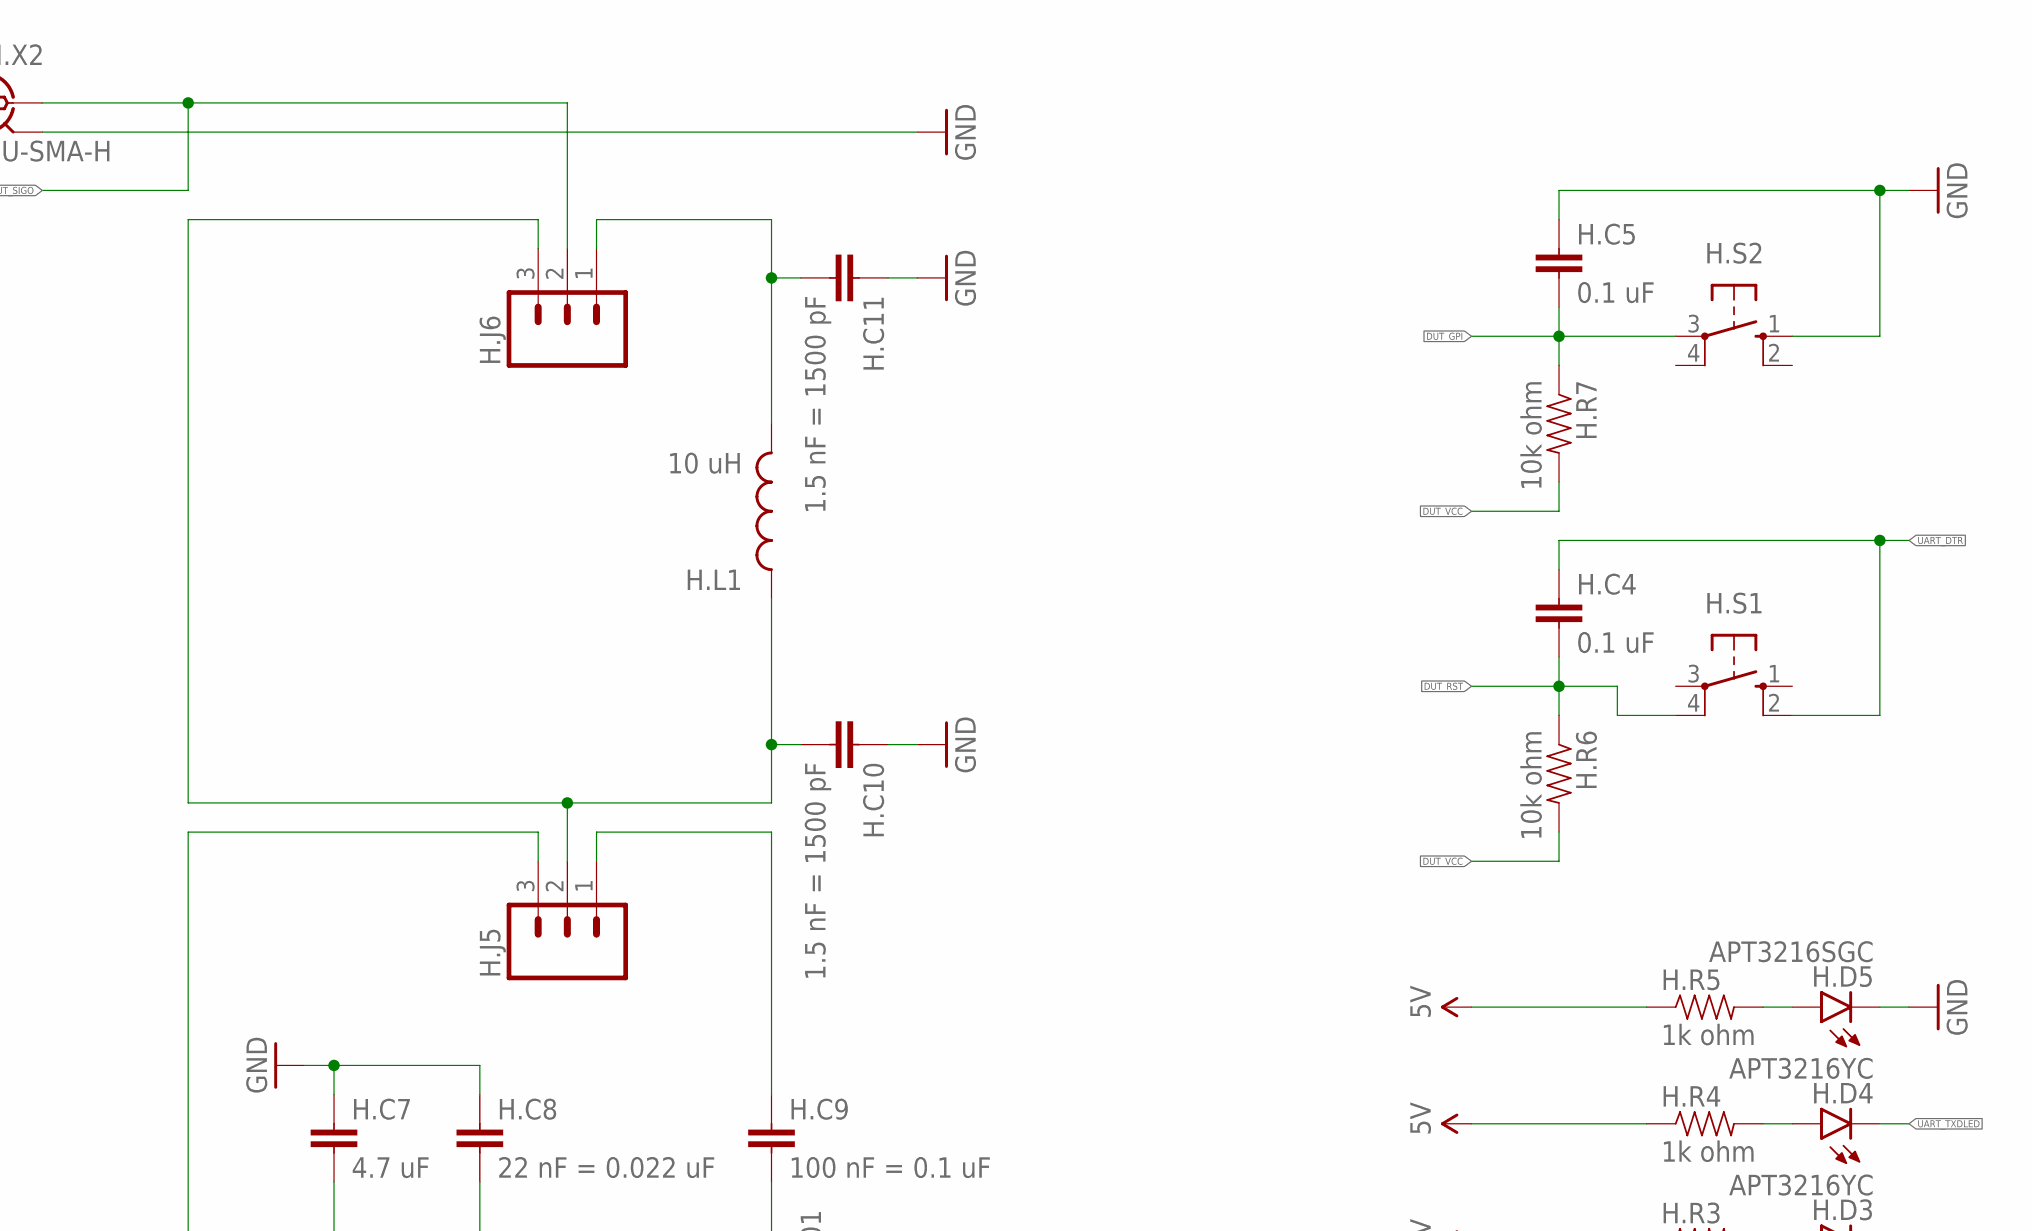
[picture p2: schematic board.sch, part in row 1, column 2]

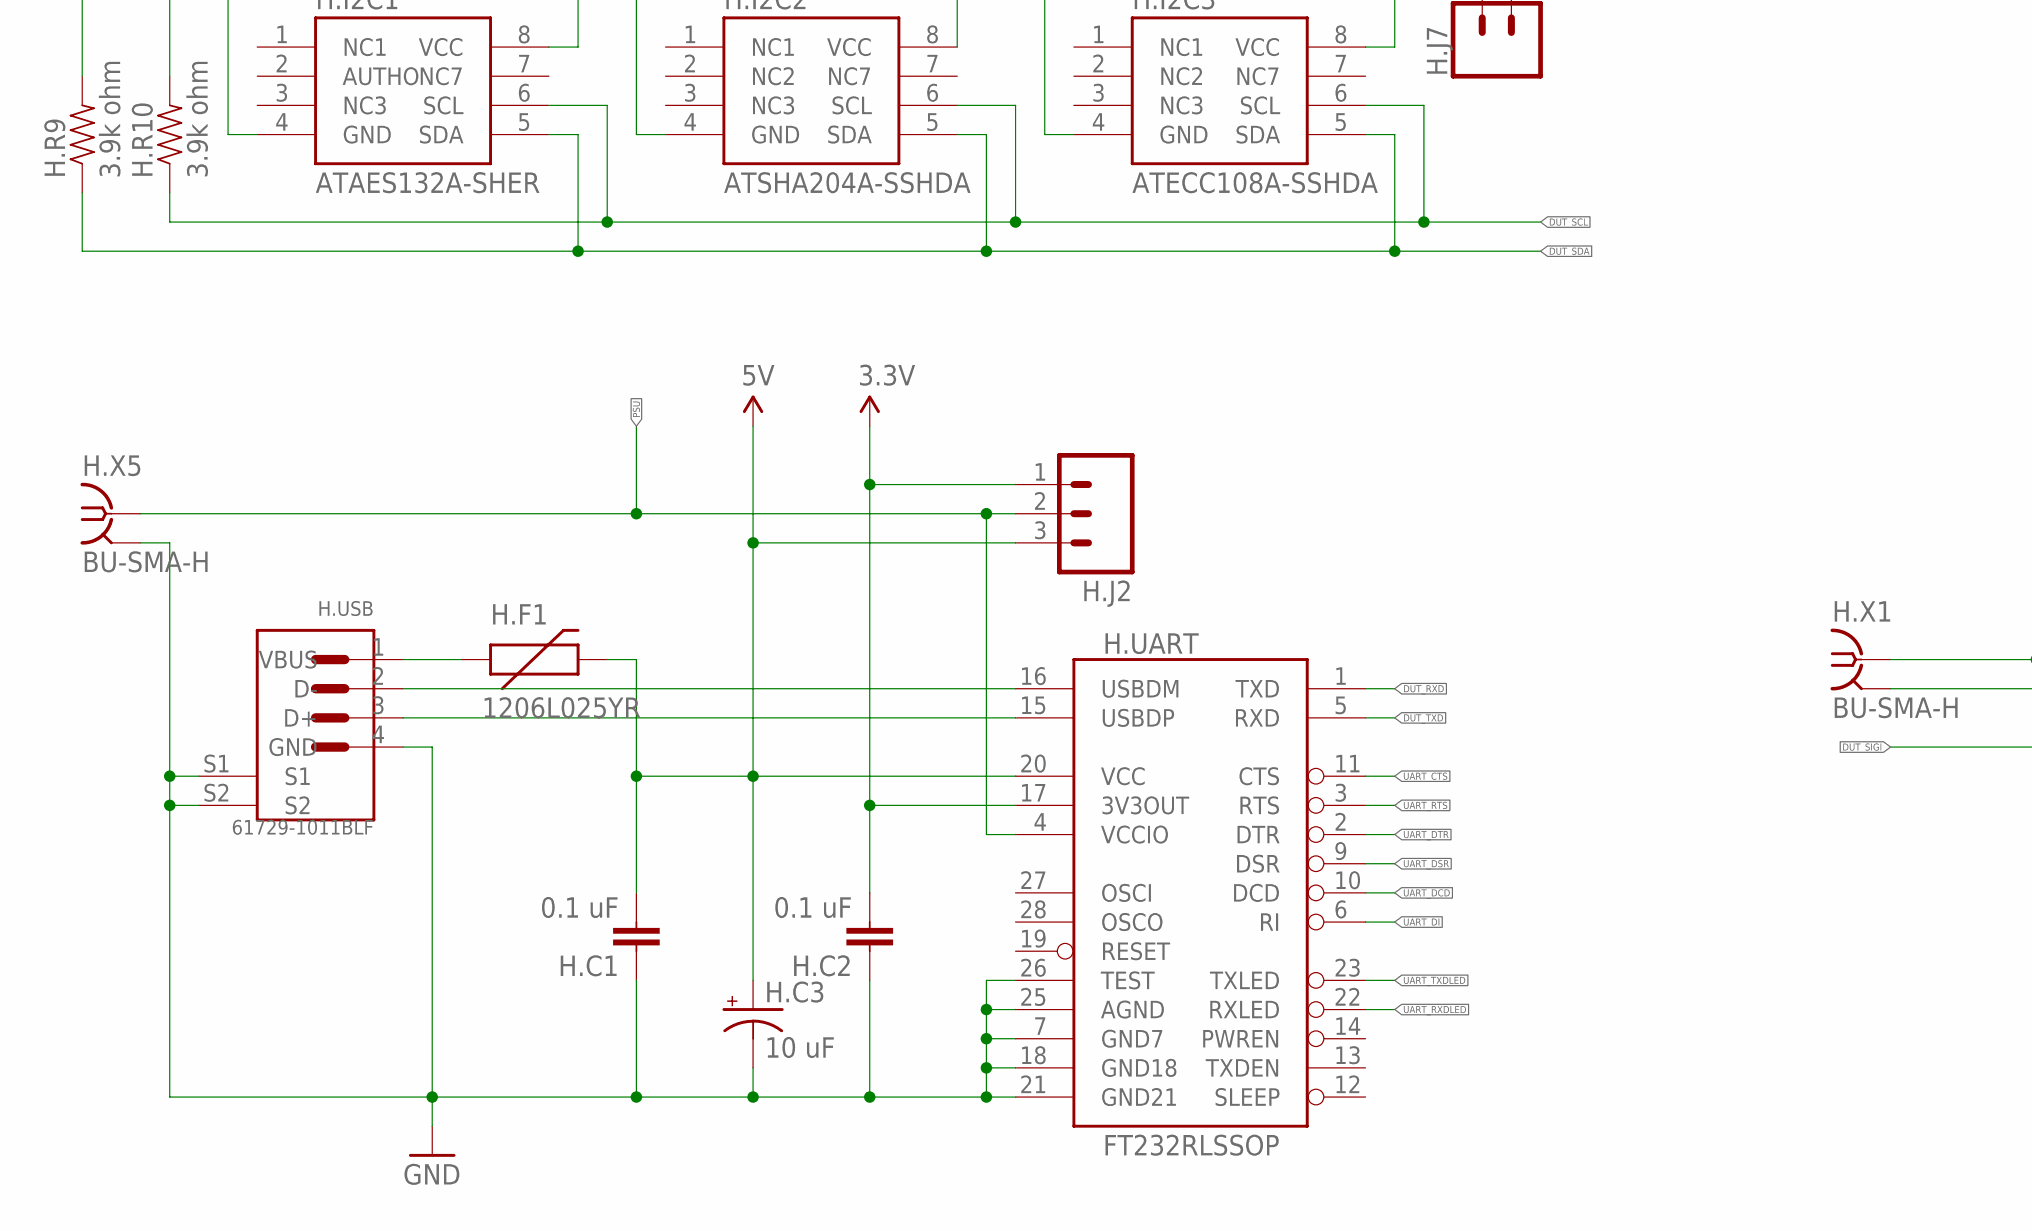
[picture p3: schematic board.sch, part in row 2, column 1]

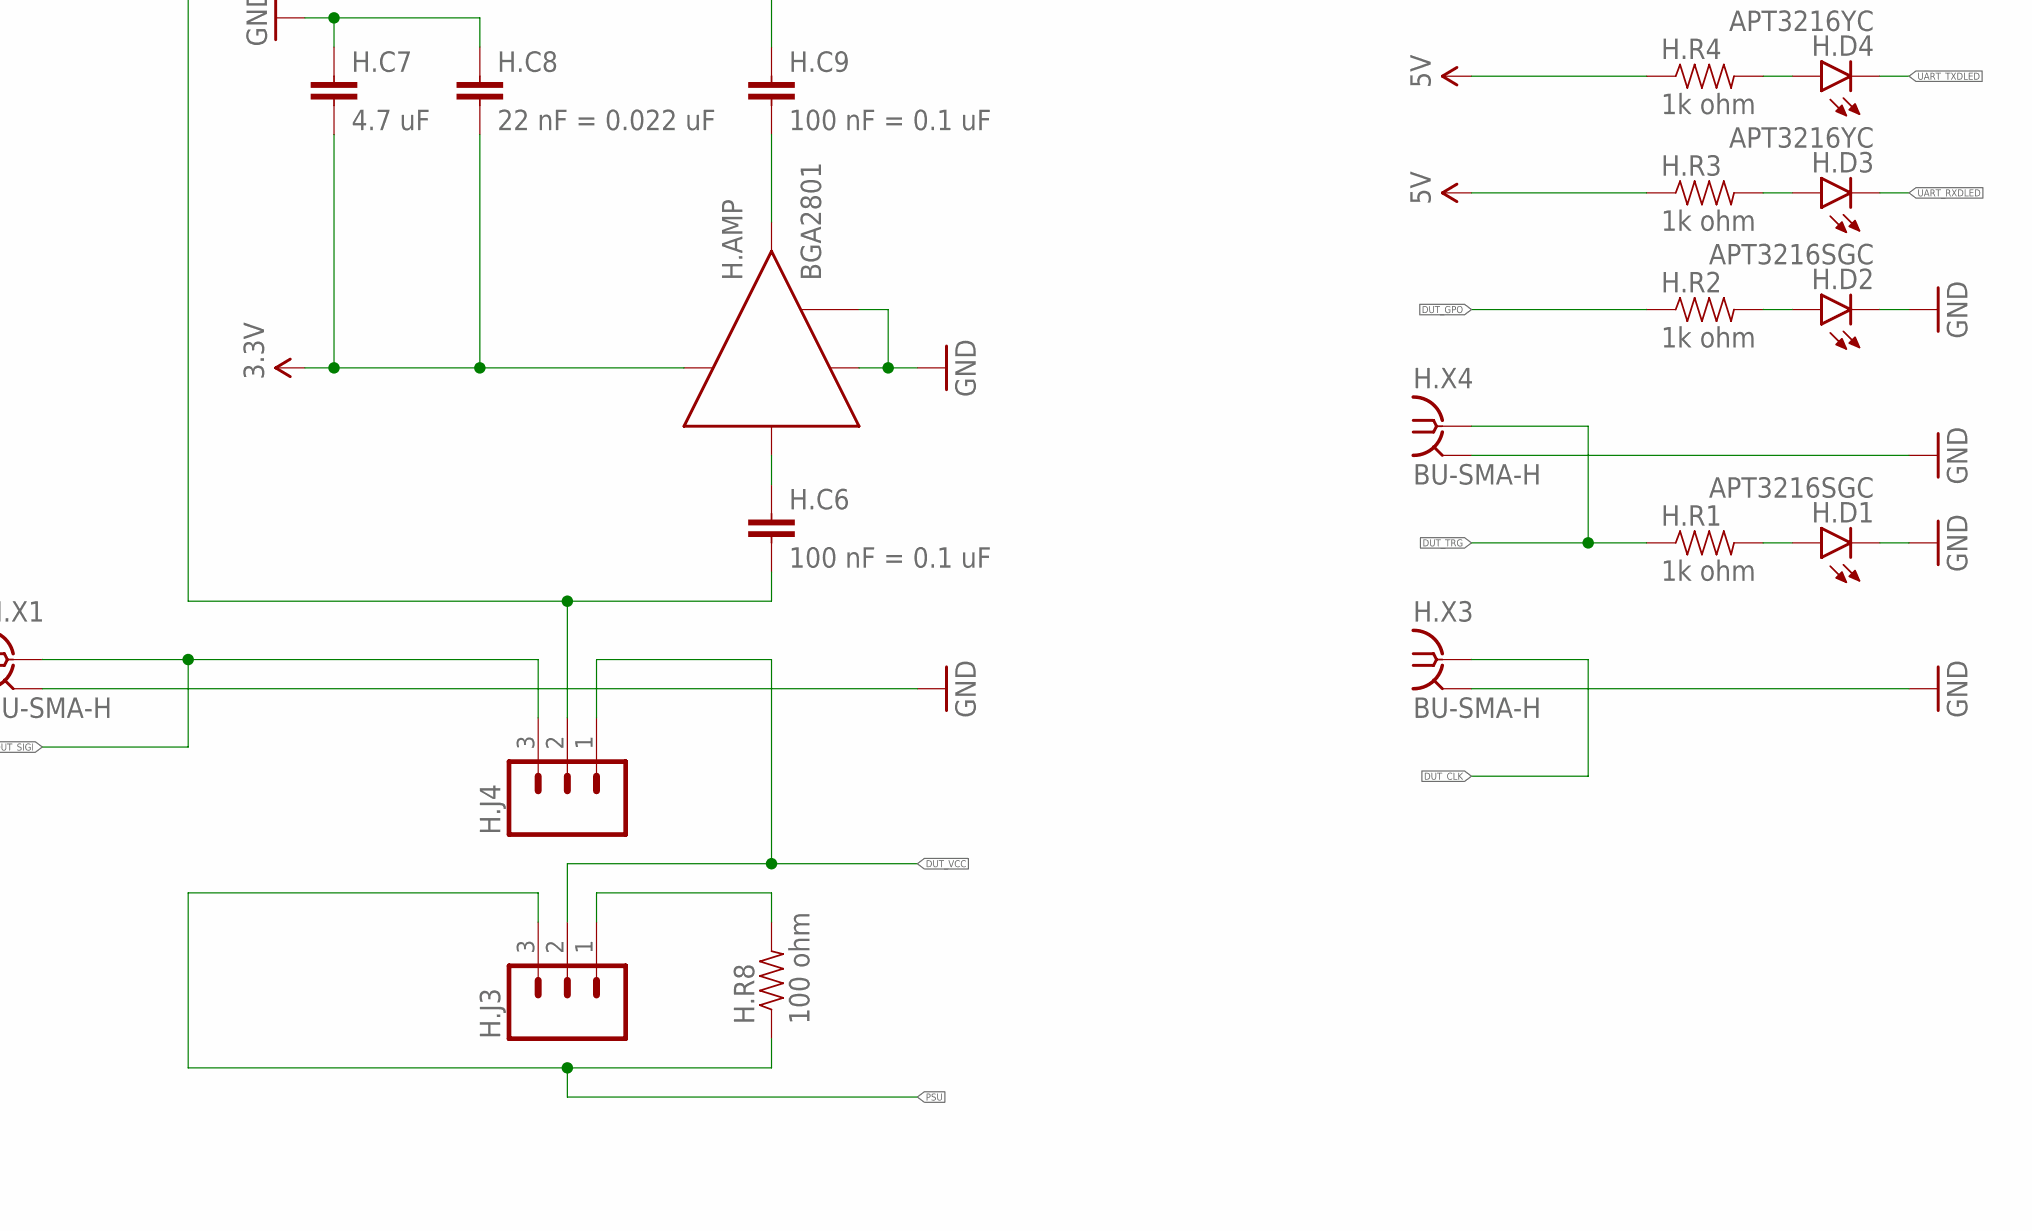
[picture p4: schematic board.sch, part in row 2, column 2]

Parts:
H.AMP: BGA2801; SOT363
H.C1, H.C2, H.C4, H.C5: 0.1 uF; 0603-CAP
H.C3: 10 uF; EIA3216
H.C6, H.C9: 100 nF = 0.1 uF; 0603-CAP
H.C7: 4.7 uF; 0603-CAP
H.C8: 22 nF = 0.022 uF; 0603-CAP
H.C10, H.C11: 1.5 nF = 1500 pF; 0603-CAP
H.D1, H.D2, H.D5: APT3216SGC; LED-1206
H.D3, H.D4: APT3216YC; LED-1206
H.F1: 1206L025YR; PTC-1206
H.H1, H.H2, H.H3, H.H4: MOUNT-PAD-ROUND3.2; 3,2-PAD
H.I2C1: ATAES132A-SHER; SO08
H.I2C2: ATSHA204A-SSHDA; SO08
H.I2C3: ATECC108A-SSHDA; SO08
H.J1L, H.J1R: CONN_16; 1X16
H.J2, H.J3, H.J4, H.J5, H.J6: M03PTH; 1X03@1
H.J7: CONN_02; 1X02
H.L1: 10 uH; 0603
H.R1, H.R2, H.R3, H.R4, H.R5: 1k ohm; 0603-RES
H.R6, H.R7: 10k ohm; 0603-RES
H.R8: 100 ohm; 0603-RES
H.R9, H.R10: 3.9k ohm; 0603-RES
H.S1, H.S2: 40-XX; B3F-40XX
H.UART: FT232RLSSOP; SSOP28DB
H.USB: 61729-1011BLF; FCI_61729-1011BLF
H.X1, H.X2, H.X3, H.X4, H.X5: BU-SMA-H

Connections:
3.3V: H.AMP.1 (VCC), H.C2.2, H.C7.2, H.C8.2, H.J2.1, H.UART.17 (3V3OUT)
5V: H.C1.2, H.C3.A (+), H.F1.2, H.J2.3, H.R3.1, H.R4.1, H.R5.1, H.UART.20 (VCC)
AMP: H.AMP.3 (RF_OUT), H.C9.2
DUT_CLK: H.J1L.9, H.X3.1
DUT_GPI: H.C5.2, H.J1R.6, H.R7.1, H.S2.3
DUT_GPO: H.J1R.8, H.R2.1
DUT_RST: H.C4.2, H.J1R.7, H.R6.1, H.S1.4 (P1)
DUT_RXD: H.J1L.12, H.UART.1 (TXD)
DUT_SCL: H.I2C1.6 (SCL), H.I2C2.6 (SCL), H.I2C3.6 (SCL), H.J1R.15, H.R10.1
DUT_SDA: H.I2C1.5 (SDA), H.I2C2.5 (SDA), H.I2C3.5 (SDA), H.J1R.14, H.R9.1
DUT_SIGI: H.J1L.2, H.J4.3, H.X1.1
DUT_SIGO: H.J1R.2, H.J6.2, H.X2.1
DUT_TRG: H.J1R.9, H.R1.1, H.X4.1
DUT_TXD: H.J1L.13, H.UART.5 (RXD)
DUT_VCC: H.J1L.5, H.J3.2, H.J4.1, H.J7.1, H.R6.2, H.R7.2
GND: H.AMP.2 (GND2), H.AMP.4 (GND1), H.AMP.5 (GND2), H.C1.1, H.C2.1, H.C3.C (-), H.C5.1, H.C7.1, H.C8.1, H.C10.1, H.C11.1, H.D1.C, H.D2.C, H.D5.C, H.H1.B3,2, H.H2.B3,2, H.H3.B3,2, H.H4.B3,2, H.I2C1.4 (GND), H.I2C2.4 (GND), H.I2C3.4 (GND), H.J1L.1, H.J1L.3, H.J1L.4, H.J1L.6, H.J1L.7, H.J1L.8, H.J1L.10, H.J1L.11, H.J1L.14, H.J1L.16, H.J1R.1, H.J1R.3, H.J1R.4, H.J1R.5, H.J1R.10, H.J1R.11, H.J1R.12, H.J1R.13, H.J1R.16, H.S2.1 (S), H.UART.7 (GND7), H.UART.18 (GND18), H.UART.21 (GND21), H.UART.25 (AGND), H.UART.26 (TEST), H.USB.4 (GND), H.USB.S1, H.USB.S2, H.X1.2, H.X1.3 (2), H.X1.4 (2), H.X1.5 (2), H.X2.2, H.X2.3 (2), H.X2.4 (2), H.X2.5 (2), H.X3.2, H.X3.3 (2), H.X3.4 (2), H.X3.5 (2), H.X4.2, H.X4.3 (2), H.X4.4 (2), H.X4.5 (2), H.X5.2, H.X5.3 (2), H.X5.4 (2), H.X5.5 (2)
unnamed: H.D5.A, H.R5.2
unnamed: H.D4.A, H.R4.2
unnamed: H.D3.A, H.R3.2
unnamed: H.D1.A, H.R1.2
unnamed: H.D2.A, H.R2.2
unnamed: H.UART.16 (USBDM), H.USB.2 (D-)
unnamed: H.UART.15 (USBDP), H.USB.3 (D+)
unnamed: H.C9.1, H.J5.1
unnamed: H.C11.2, H.J6.1, H.L1.2
unnamed: H.C10.2, H.J5.2, H.J6.3, H.L1.1
unnamed: H.J3.1, H.R8.2
unnamed: H.F1.1, H.USB.1 (VBUS)
unnamed: H.I2C1.8 (VCC), H.I2C2.8 (VCC), H.I2C3.8 (VCC), H.J7.2, H.R9.2, H.R10.2
unnamed: H.AMP.6 (RF_IN), H.C6.1
unnamed: H.C6.2, H.J4.2, H.J5.3
PSU: H.J1L.15, H.J2.2, H.J3.3, H.R8.1, H.UART.4 (VCCIO), H.X5.1
UART_CTS: H.UART.11 (CTS)
UART_DCD: H.UART.10 (DCD)
UART_DI: H.UART.6 (RI)
UART_DSR: H.UART.9 (DSR)
UART_DTR: H.C4.1, H.S1.2 (S1), H.UART.2 (DTR)
UART_RTS: H.UART.3 (RTS)
UART_RXDLED: H.D3.C, H.UART.22 (RXLED)
UART_TXDLED: H.D4.C, H.UART.23 (TXLED)

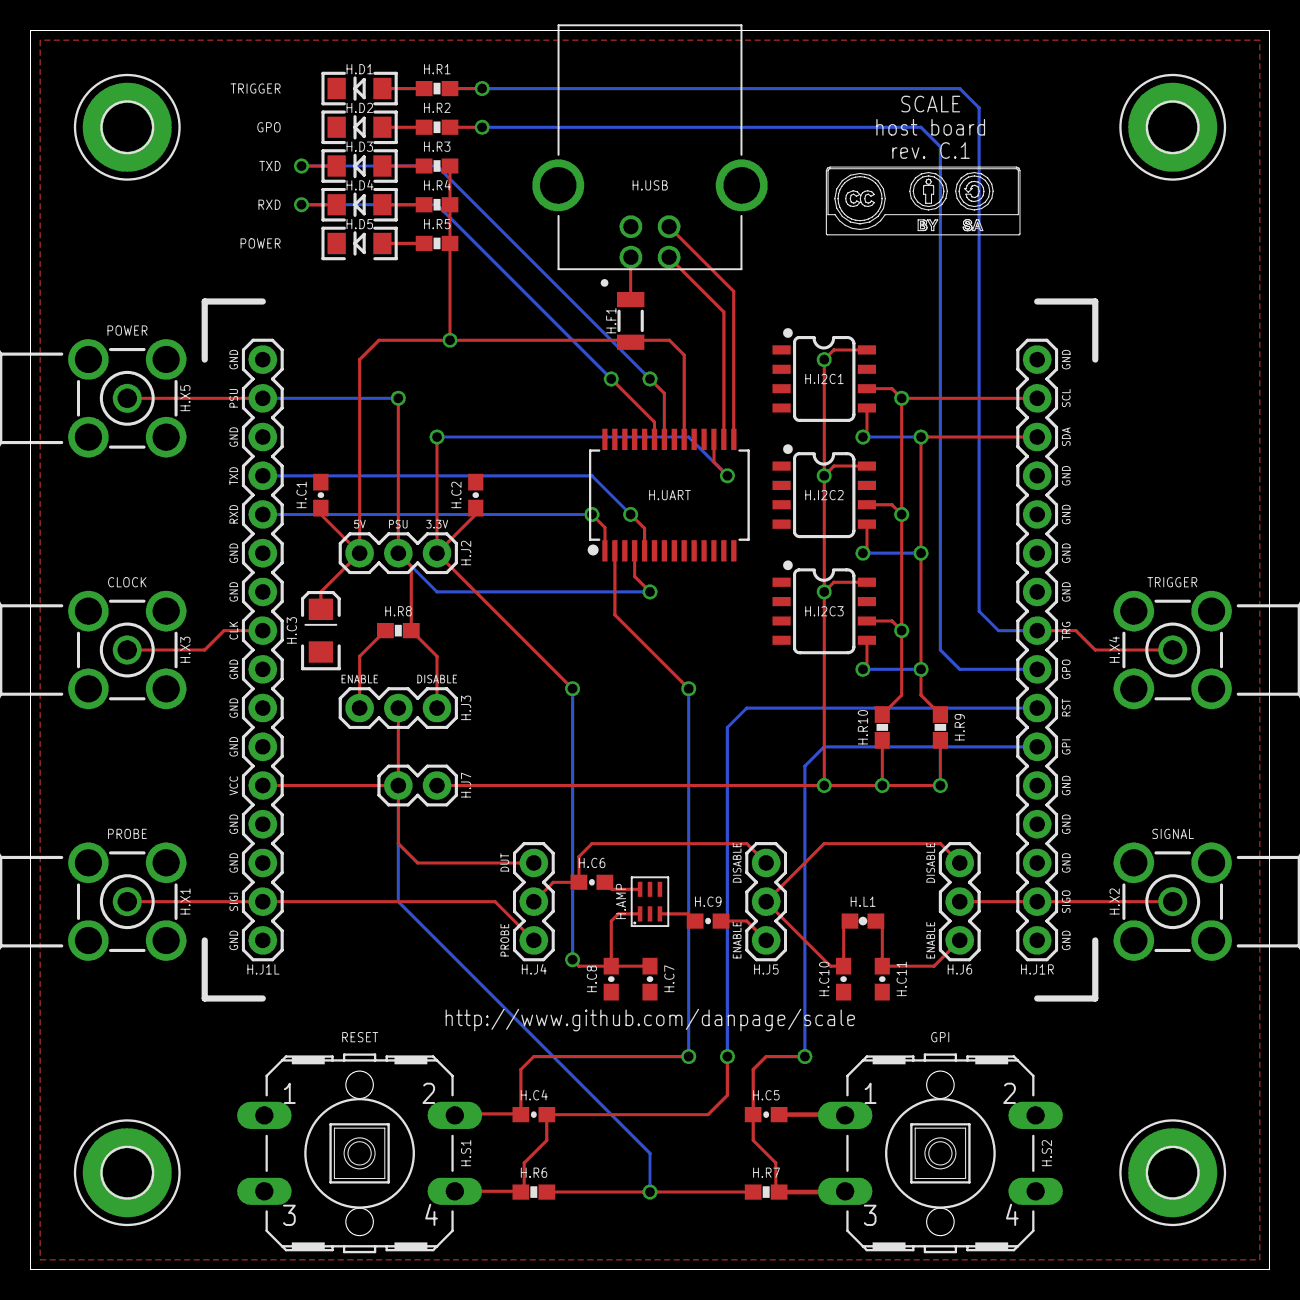
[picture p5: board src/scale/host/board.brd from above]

Board: 2 copper layers, 81.3 x 81.3 mm, 53 parts (0 on the bottom side), 35 nets.

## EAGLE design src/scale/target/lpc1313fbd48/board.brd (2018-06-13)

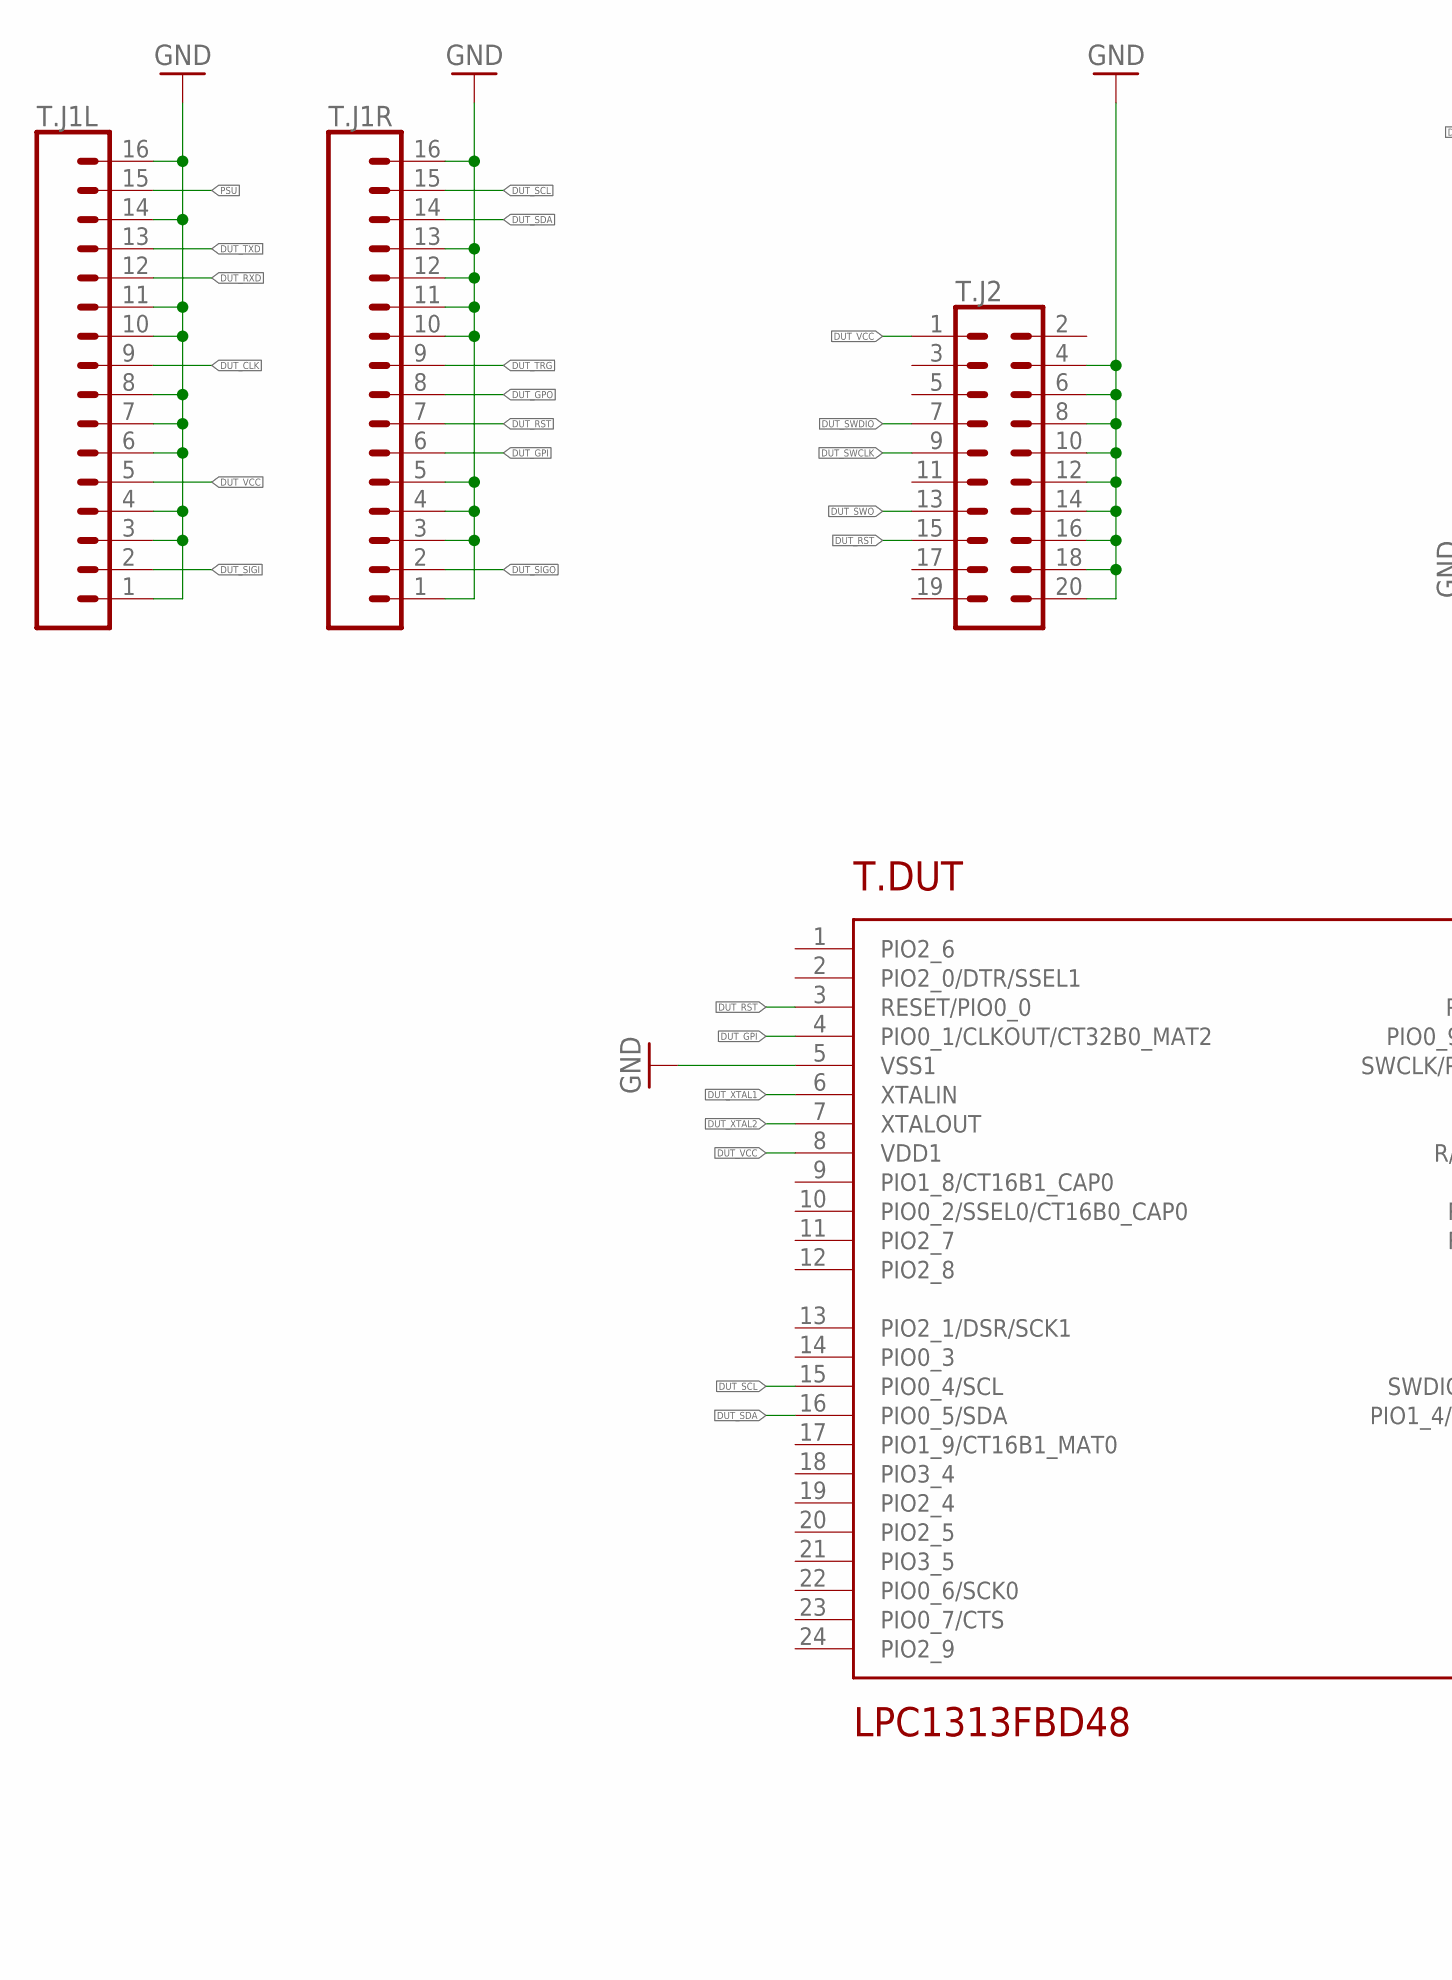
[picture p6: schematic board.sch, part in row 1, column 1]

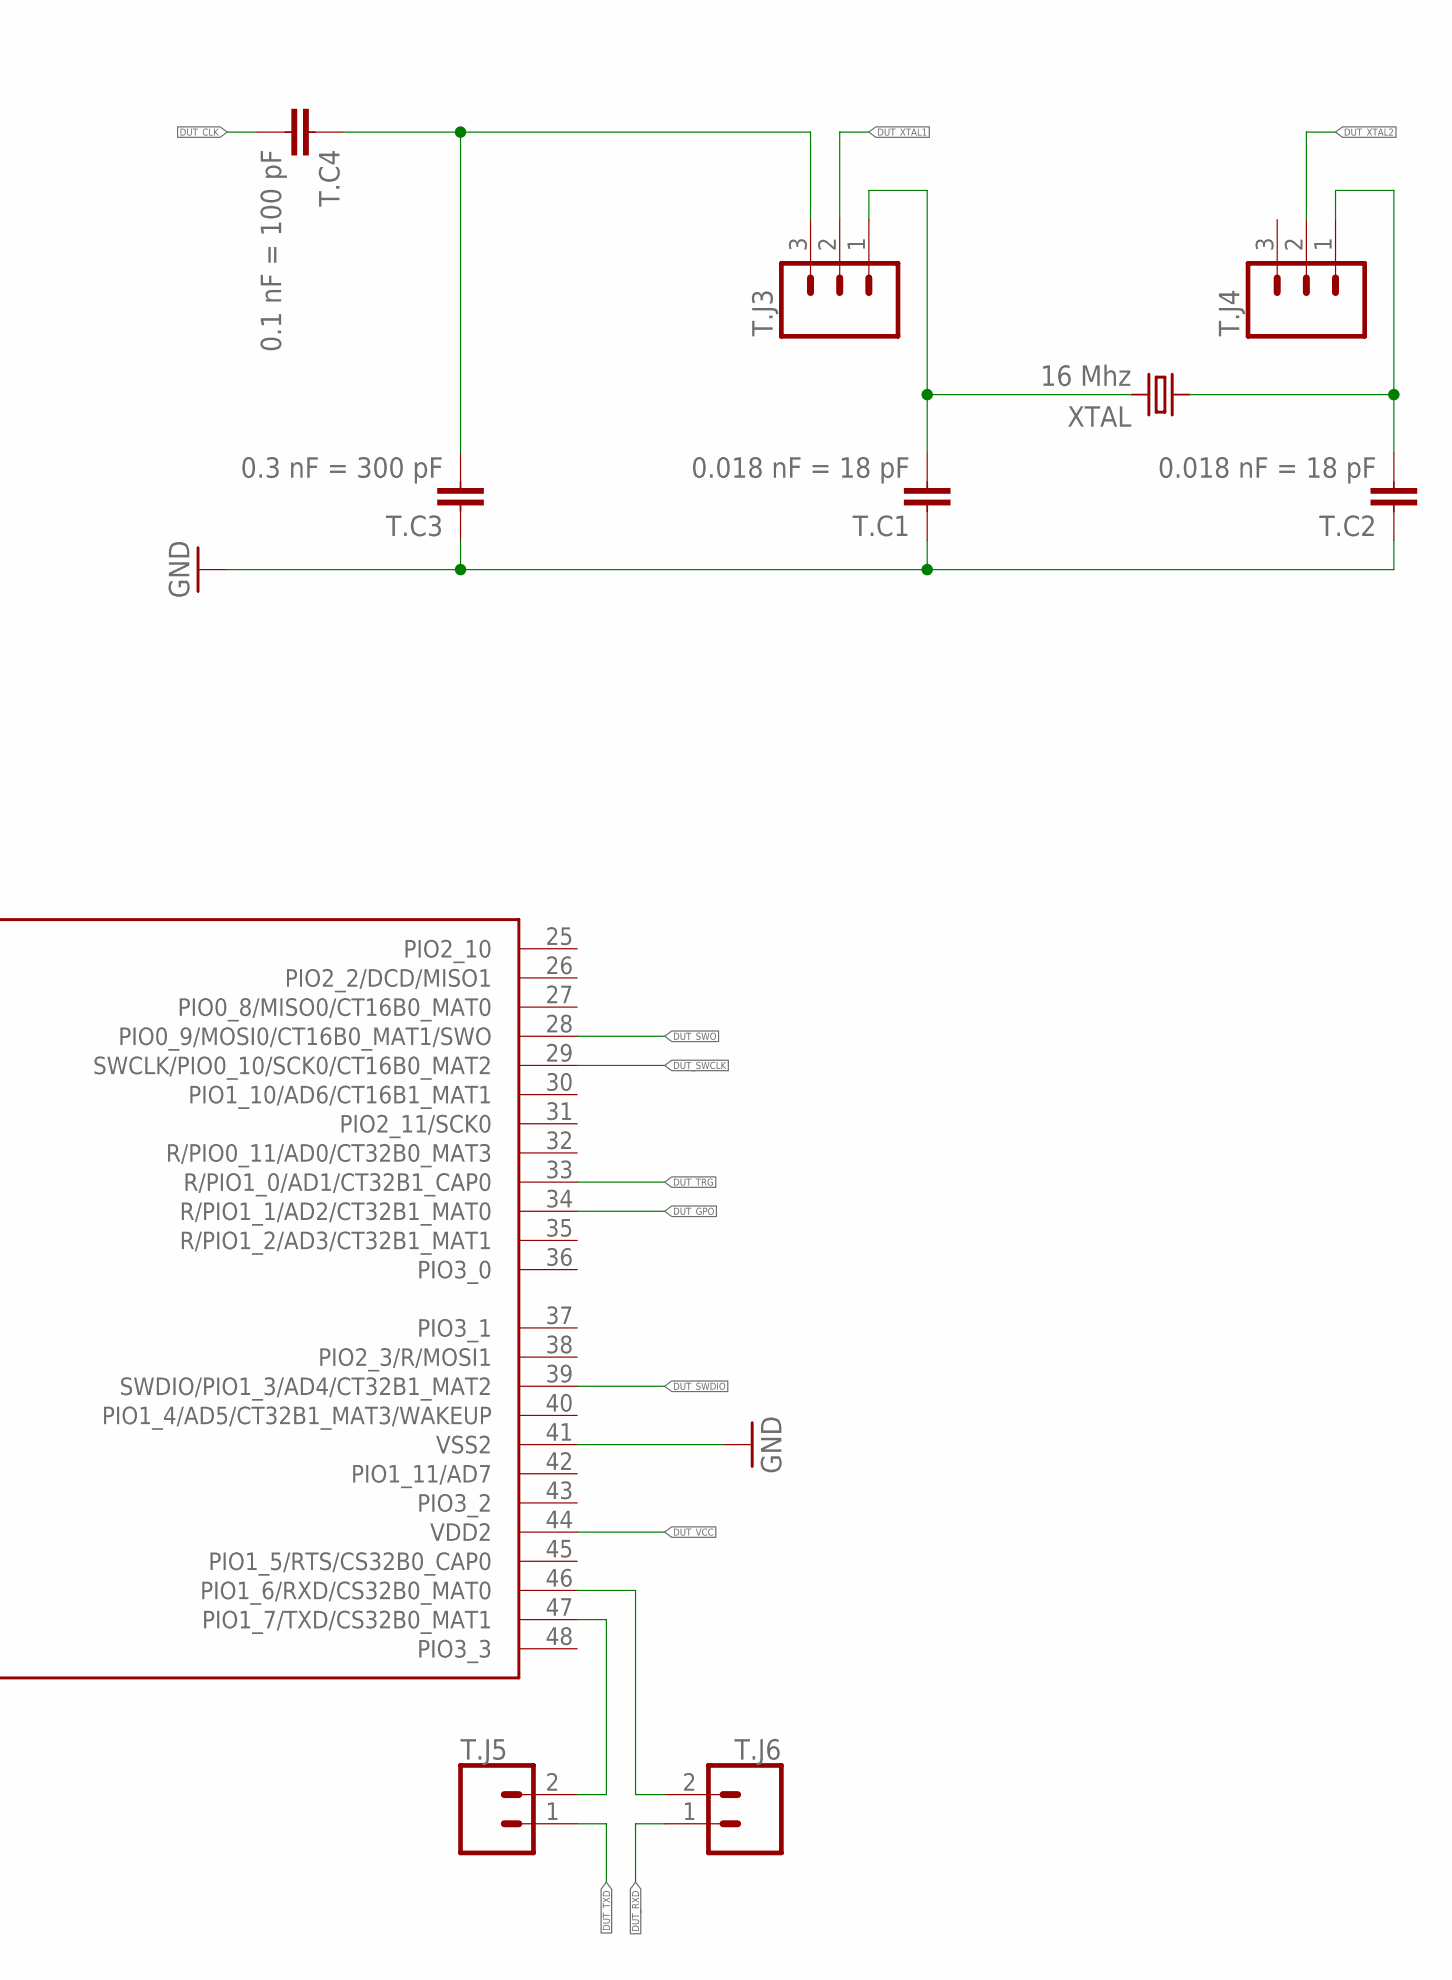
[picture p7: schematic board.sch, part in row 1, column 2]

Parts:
T.C1, T.C2: 0.018 nF = 18 pF; 0603-CAP
T.C3: 0.3 nF = 300 pF; 0603-CAP
T.C4: 0.1 nF = 100 pF; 0603-CAP
T.DUT: LPC1313FBD48; LQFP48
T.J1L, T.J1R: CONN_16; 1X16
T.J2: CONN_10X2; 2X10
T.J3, T.J4: M03PTH; 1X03
T.J5, T.J6: CONN_02; 1X02
XTAL: 16 Mhz; HC49US

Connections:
DUT_CLK: T.C4.2, T.J1L.9
DUT_GPI: T.DUT.4 (PIO0_1/CLKOUT/CT32B0_MAT2), T.J1R.6
DUT_GPO: T.DUT.34 (R/PIO1_1/AD2/CT32B1_MAT0), T.J1R.8
DUT_RST: T.DUT.3 (RESET/PIO0_0), T.J1R.7, T.J2.15
DUT_RXD: T.J1L.12, T.J6.1
DUT_SCL: T.DUT.15 (PIO0_4/SCL), T.J1R.15
DUT_SDA: T.DUT.16 (PIO0_5/SDA), T.J1R.14
DUT_SIGI: T.J1L.2
DUT_SIGO: T.J1R.2
DUT_SWCLK: T.DUT.29 (SWCLK/PIO0_10/SCK0/CT16B0_MAT2), T.J2.9
DUT_SWDIO: T.DUT.39 (SWDIO/PIO1_3/AD4/CT32B1_MAT2), T.J2.7
DUT_SWO: T.DUT.28 (PIO0_9/MOSI0/CT16B0_MAT1/SWO), T.J2.13
DUT_TRG: T.DUT.33 (R/PIO1_0/AD1/CT32B1_CAP0), T.J1R.9
DUT_TXD: T.J1L.13, T.J5.1
DUT_VCC: T.DUT.8 (VDD1), T.DUT.44 (VDD2), T.J1L.5, T.J2.1
DUT_XTAL1: T.DUT.6 (XTALIN), T.J3.2
DUT_XTAL2: T.DUT.7 (XTALOUT), T.J4.2
GND: T.C1.1, T.C2.1, T.C3.1, T.DUT.5 (VSS1), T.DUT.41 (VSS2), T.J1L.1, T.J1L.3, T.J1L.4, T.J1L.6, T.J1L.7, T.J1L.8, T.J1L.10, T.J1L.11, T.J1L.14, T.J1L.16, T.J1R.1, T.J1R.3, T.J1R.4, T.J1R.5, T.J1R.10, T.J1R.11, T.J1R.12, T.J1R.13, T.J1R.16, T.J2.4, T.J2.6, T.J2.8, T.J2.10, T.J2.12, T.J2.14, T.J2.16, T.J2.18, T.J2.20
unnamed: T.C1.2, T.J3.1, XTAL.2
unnamed: T.C2.2, T.J4.1, XTAL.1
unnamed: T.DUT.47 (PIO1_7/TXD/CS32B0_MAT1), T.J5.2
unnamed: T.DUT.46 (PIO1_6/RXD/CS32B0_MAT0), T.J6.2
unnamed: T.C3.2, T.C4.1, T.J3.3
PSU: T.J1L.15

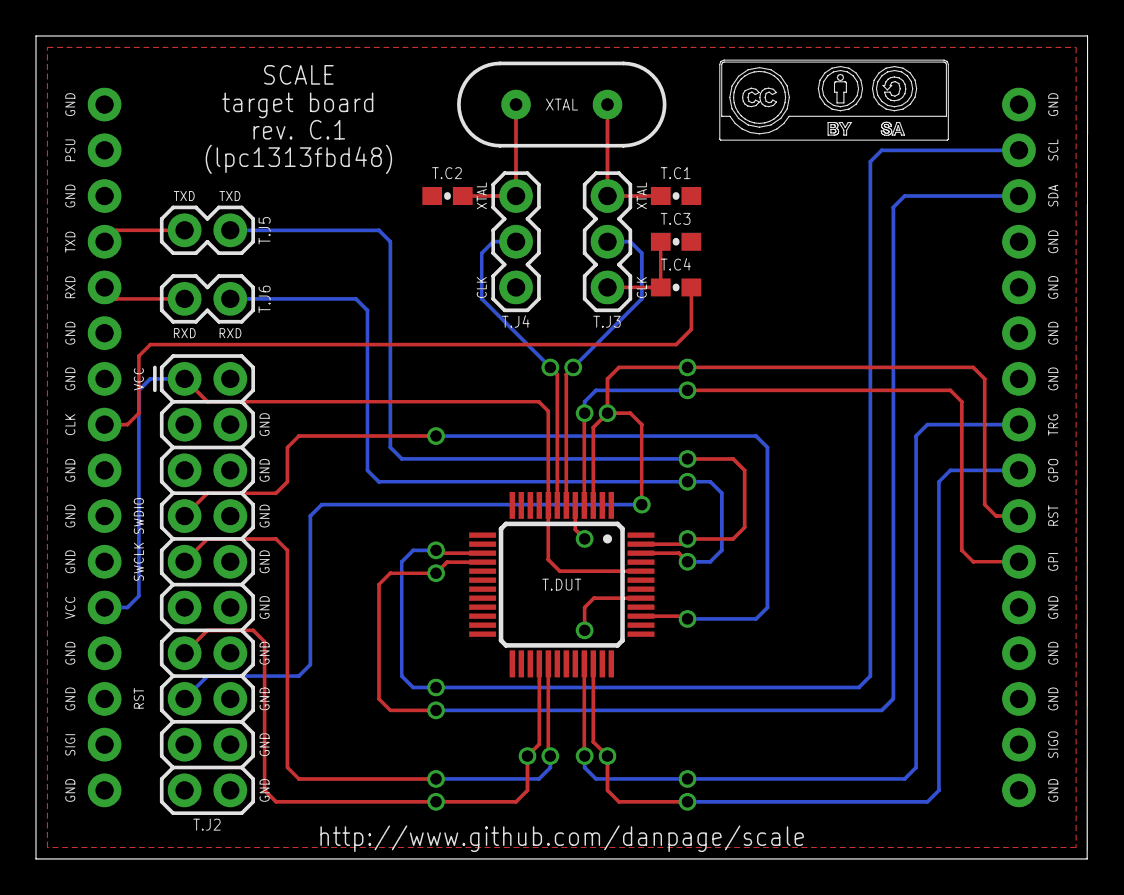
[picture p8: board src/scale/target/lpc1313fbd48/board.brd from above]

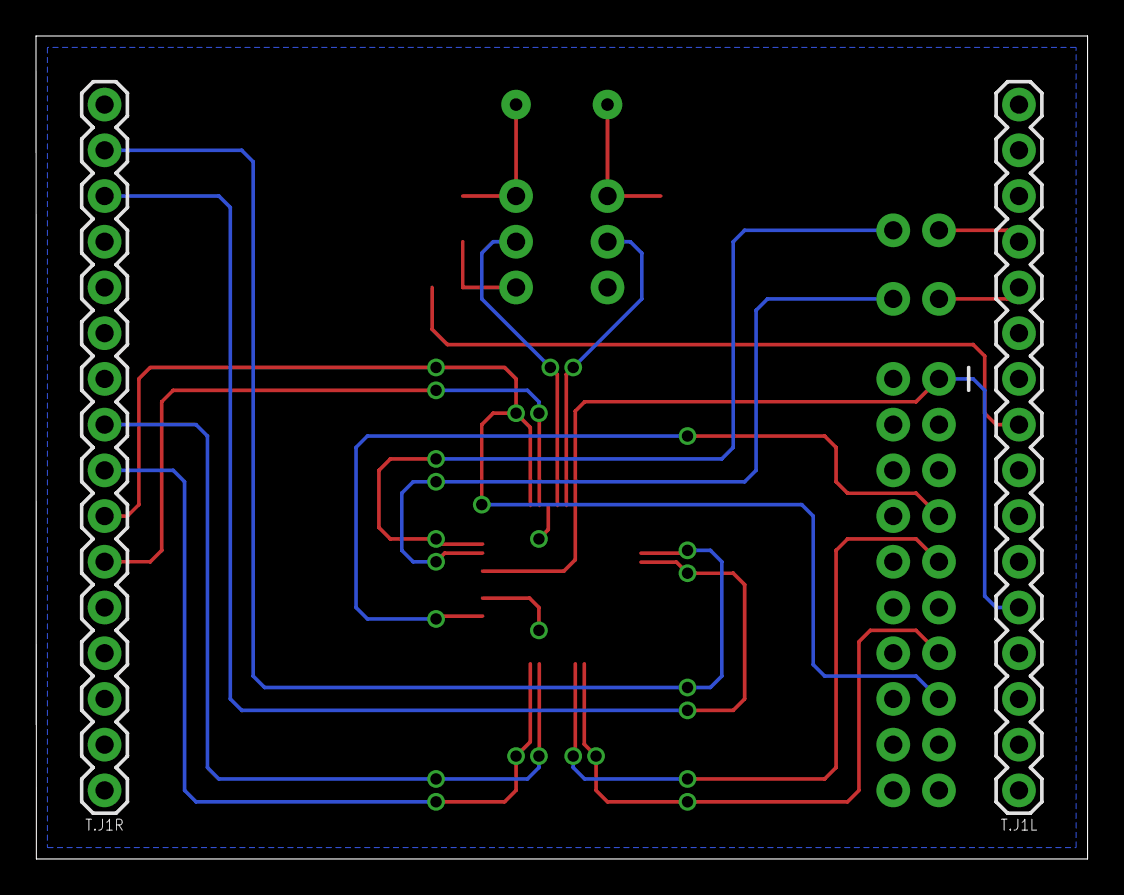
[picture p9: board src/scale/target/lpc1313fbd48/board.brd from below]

Board: 2 copper layers, 58.4 x 45.7 mm, 13 parts (2 on the bottom side), 21 nets.

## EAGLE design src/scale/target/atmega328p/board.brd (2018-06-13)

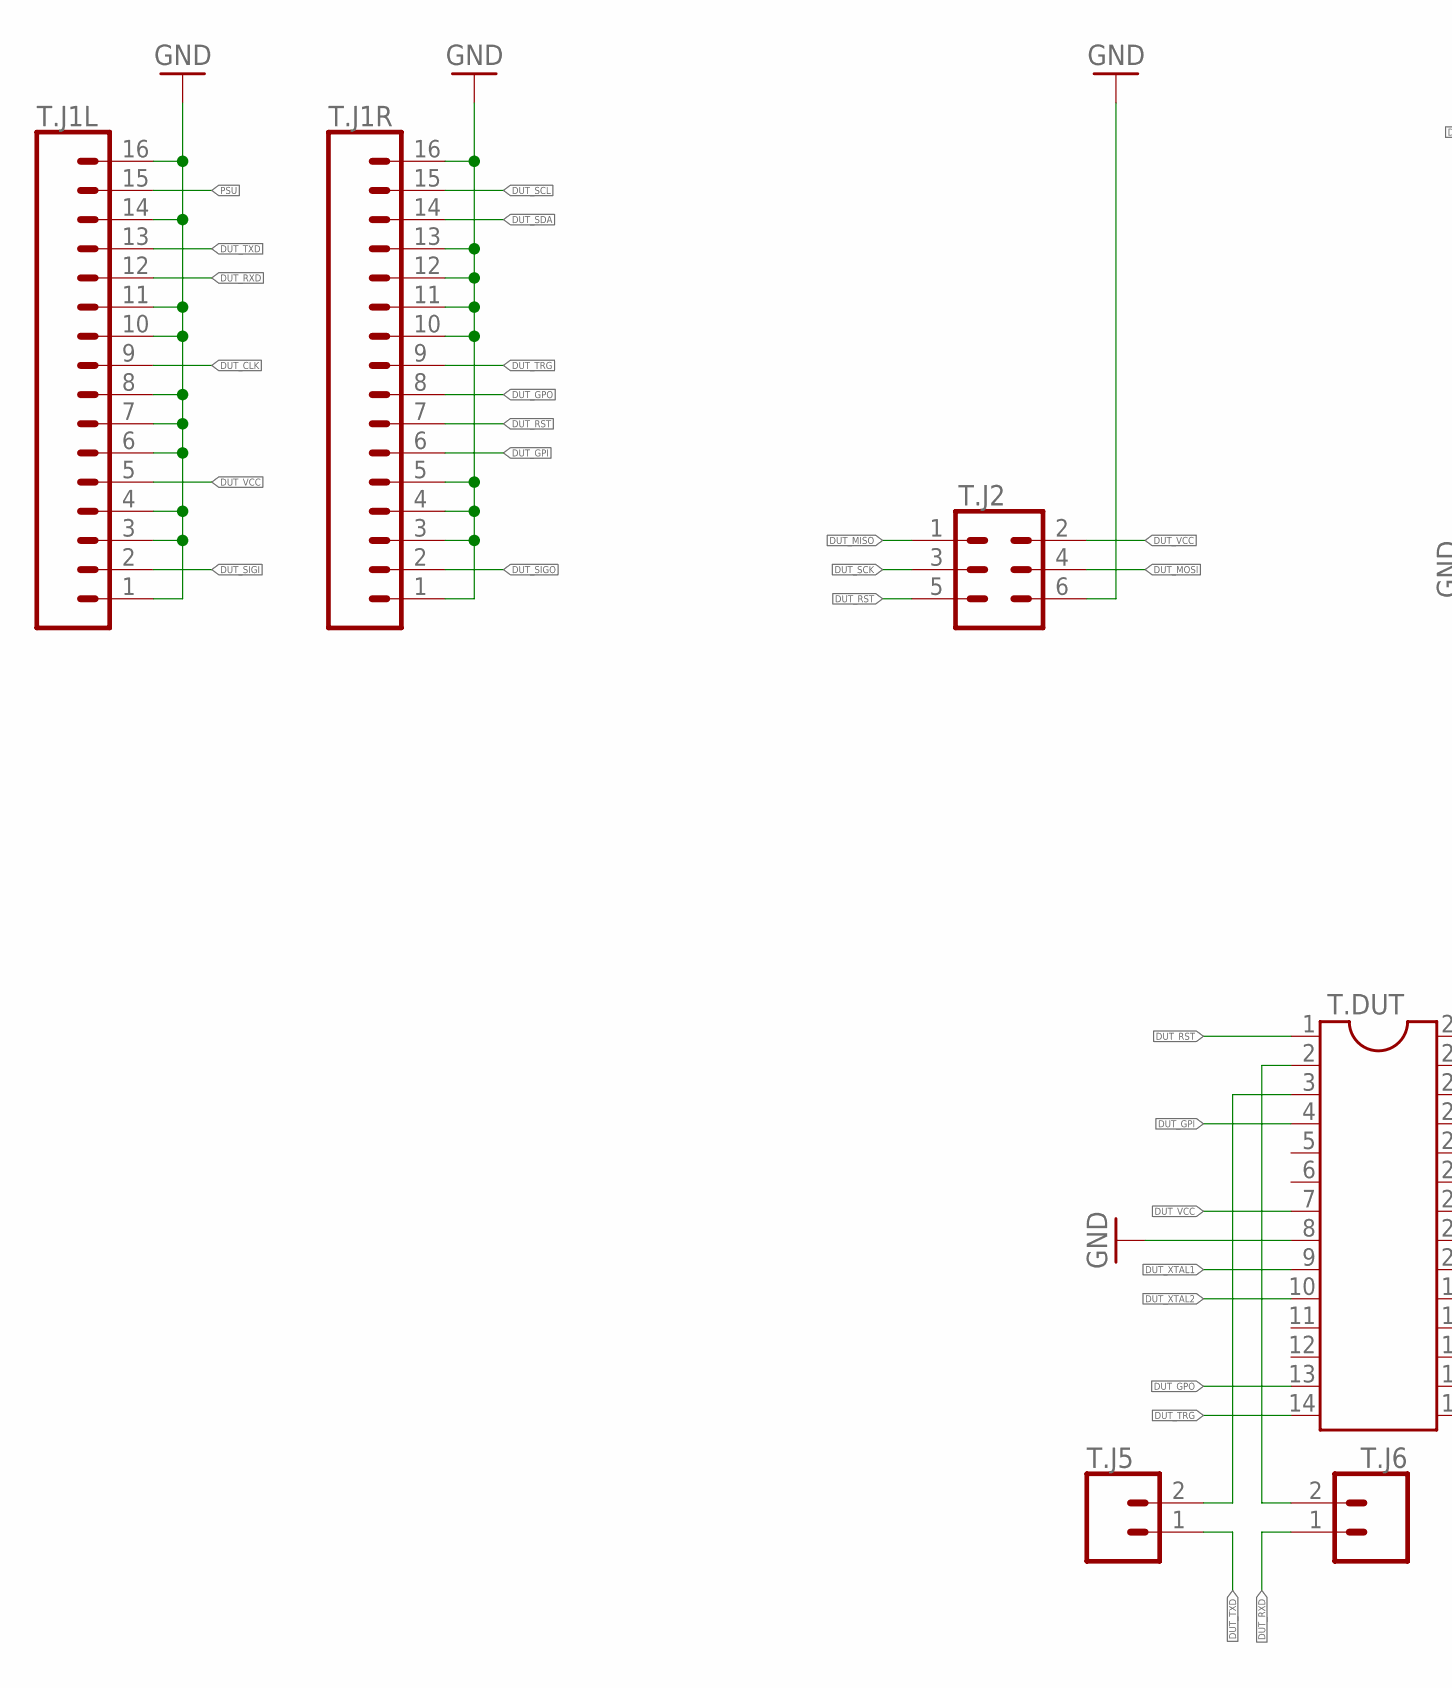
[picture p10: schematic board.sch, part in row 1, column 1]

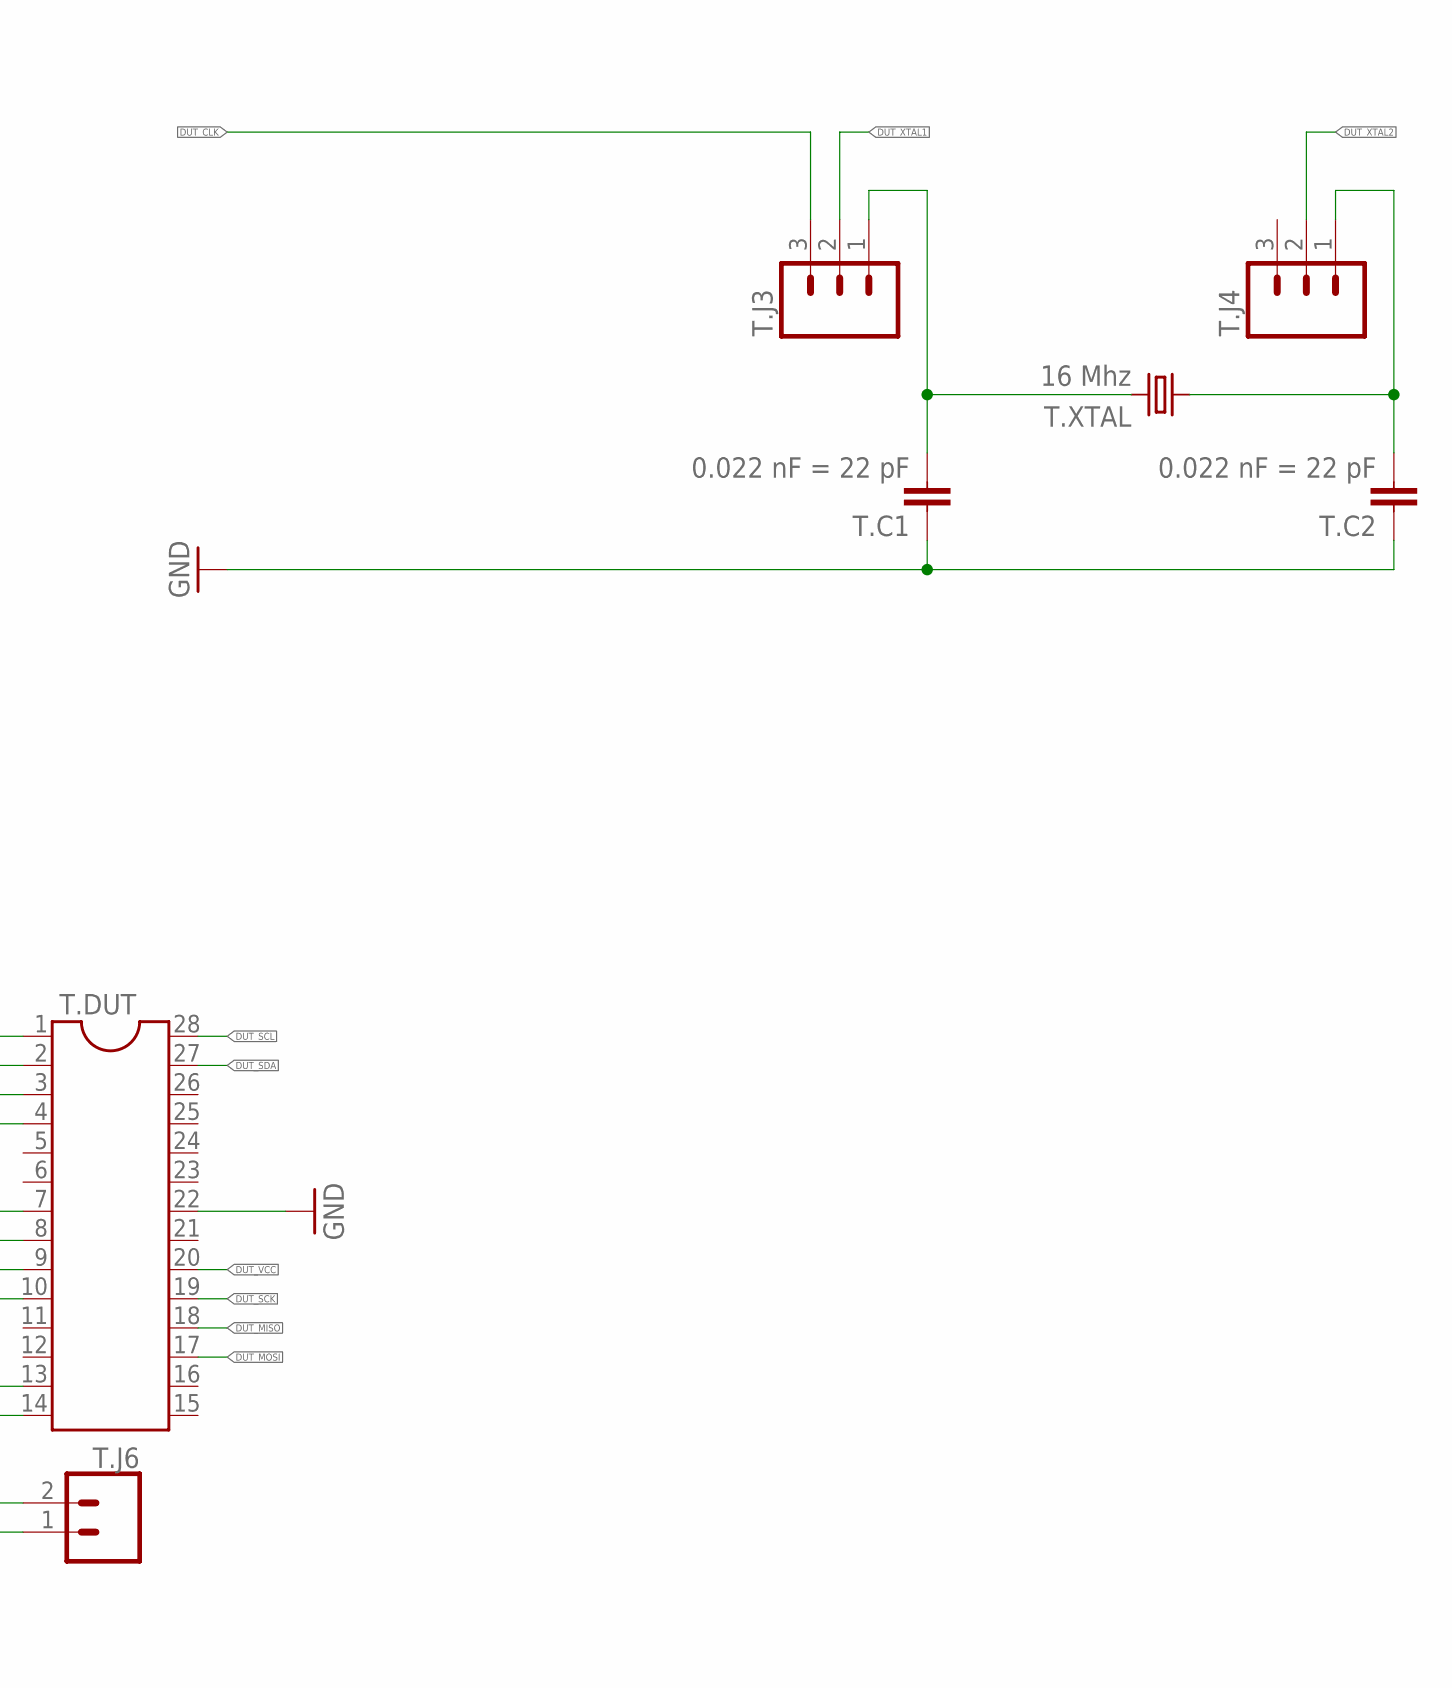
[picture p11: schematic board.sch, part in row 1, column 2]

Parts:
T.C1, T.C2: 0.022 nF = 22 pF; 0603-CAP
T.DUT: DIL28-3
T.J1L, T.J1R: CONN_16; 1X16
T.J2: CONN_03X22X3_SILK_MALE_PTH; 2X3
T.J3, T.J4: M03PTH; 1X03
T.J5, T.J6: CONN_02; 1X02
T.XTAL: 16 Mhz; HC49US

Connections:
DUT_CLK: T.J1L.9, T.J3.3
DUT_GPI: T.DUT.4, T.J1R.6
DUT_GPO: T.DUT.13, T.J1R.8
DUT_MISO: T.DUT.18, T.J2.1
DUT_MOSI: T.DUT.17, T.J2.4
DUT_RST: T.DUT.1, T.J1R.7, T.J2.5
DUT_RXD: T.J1L.12, T.J6.1
DUT_SCK: T.DUT.19, T.J2.3
DUT_SCL: T.DUT.28, T.J1R.15
DUT_SDA: T.DUT.27, T.J1R.14
DUT_SIGI: T.J1L.2
DUT_SIGO: T.J1R.2
DUT_TRG: T.DUT.14, T.J1R.9
DUT_TXD: T.J1L.13, T.J5.1
DUT_VCC: T.DUT.7, T.DUT.20, T.J1L.5, T.J2.2
DUT_XTAL1: T.DUT.9, T.J3.2
DUT_XTAL2: T.DUT.10, T.J4.2
GND: T.C1.1, T.C2.1, T.DUT.8, T.DUT.22, T.J1L.1, T.J1L.3, T.J1L.4, T.J1L.6, T.J1L.7, T.J1L.8, T.J1L.10, T.J1L.11, T.J1L.14, T.J1L.16, T.J1R.1, T.J1R.3, T.J1R.4, T.J1R.5, T.J1R.10, T.J1R.11, T.J1R.12, T.J1R.13, T.J1R.16, T.J2.6
unnamed: T.C1.2, T.J3.1, T.XTAL.2
unnamed: T.C2.2, T.J4.1, T.XTAL.1
unnamed: T.DUT.3, T.J5.2
unnamed: T.DUT.2, T.J6.2
PSU: T.J1L.15

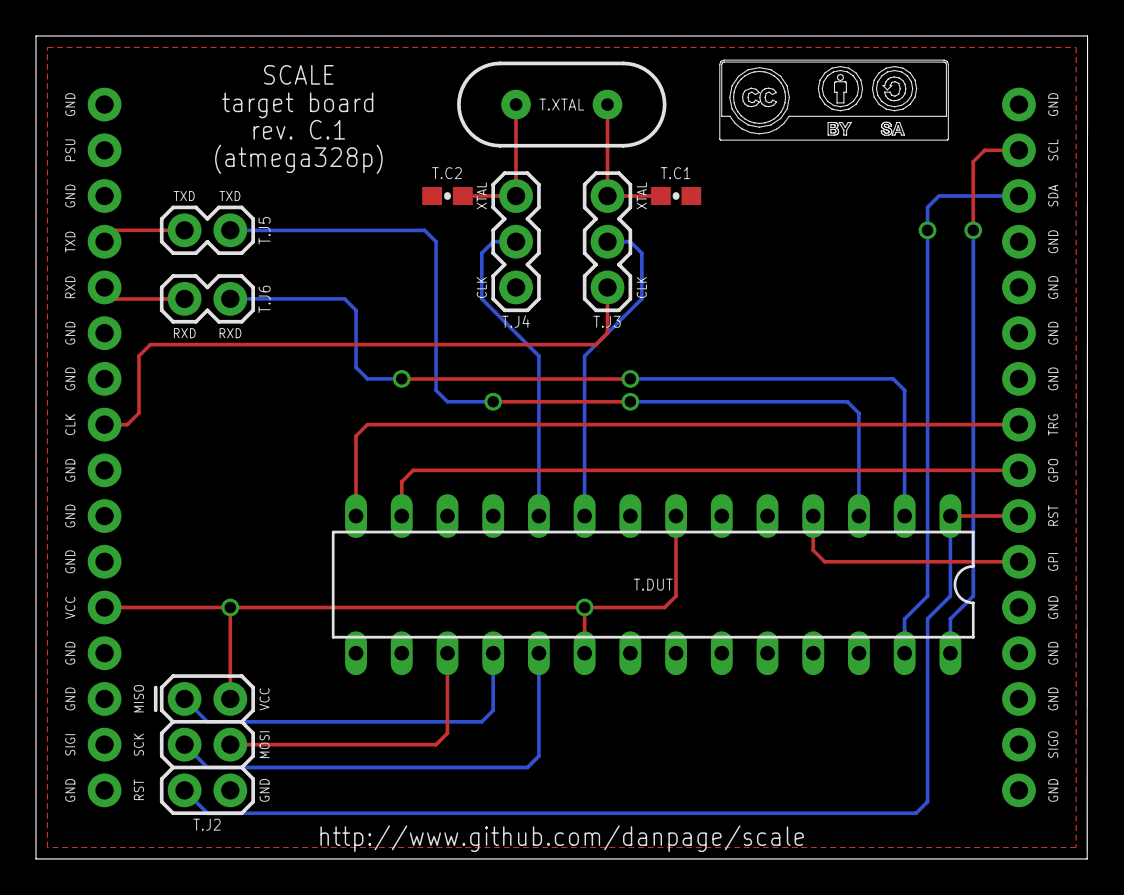
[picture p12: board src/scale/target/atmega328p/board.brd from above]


Board: 2 copper layers, 58.4 x 45.7 mm, 11 parts (2 on the bottom side), 20 nets.

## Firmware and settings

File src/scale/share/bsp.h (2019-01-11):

/* Copyright (C) 2017 Daniel Page <dan@phoo.org>
 *
 * Use of this source code is restricted per the CC BY-SA license, a copy of
 * which can be found via http://creativecommons.org (and should be included 
 * as LICENSE.txt within the associated archive or repository).
 */

#ifndef __BSP_H
#define __BSP_H

#include <stdbool.h>
#include  <stdint.h>
#include  <string.h>

#define RSVD(x,y,z) uint8_t reserved_##x[ z - y + 1 ]

#define RO volatile const /* read  only */
#define WO volatile       /* write only */
#define RW volatile       /* read/write */
#define WR volatile       /* write/read */

typedef enum {
  SCALE_CLOCK_TYPE_INT   =  0, // internal  clock
  SCALE_CLOCK_TYPE_EXT   =  1, // external  clock, i.e., crystal
  SCALE_CLOCK_TYPE_PIN   =  2  // generated clock, i.e., via frequency generator
} scale_clock_type_t;

typedef enum {
  SCALE_CLOCK_FREQ_1MHZ  =  1,
  SCALE_CLOCK_FREQ_2MHZ  =  2,
  SCALE_CLOCK_FREQ_4MHZ  =  4,
  SCALE_CLOCK_FREQ_8MHZ  =  8,
  SCALE_CLOCK_FREQ_12MHZ = 12,
  SCALE_CLOCK_FREQ_16MHZ = 16,
  SCALE_CLOCK_FREQ_24MHZ = 24,
  SCALE_CLOCK_FREQ_32MHZ = 32
} scale_clock_freq_t;

typedef uint64_t scale_tsc_t;

typedef enum {
  SCALE_GPIO_PIN_TRG,
  SCALE_GPIO_PIN_GPO,
  SCALE_GPIO_PIN_GPI
} scale_gpio_pin_t;

typedef enum {
  SCALE_UART_MODE_BLOCKING,
  SCALE_UART_MODE_NONBLOCKING,
} scale_uart_mode_t;

typedef uint8_t scale_i2c_addr_t;

typedef enum {
  SCALE_I2C_MODE_WR = 0x00,
  SCALE_I2C_MODE_RD = 0x01
} scale_i2c_mode_t;

typedef enum { 
  SCALE_I2C_STATUS_SUCCESS           = 0x00,
  SCALE_I2C_STATUS_FAILURE           = 0x01,
  SCALE_I2C_STATUS_FAILURE_NACK_ADDR = 0x02,
  SCALE_I2C_STATUS_FAILURE_NACK_DATA = 0x03
} scale_i2c_status_t;

typedef struct {
  scale_clock_type_t clock_type;
  scale_clock_freq_t clock_freq_source;
  scale_clock_freq_t clock_freq_target;

  bool               tsc;
} scale_conf_t;

// default configuration
extern scale_conf_t SCALE_CONF;
// active  configuration
extern scale_conf_t scale_conf;

// initialise (e.g., clocks, GPIO, UART, I2C, etc.)
extern bool               scale_init( scale_conf_t* conf );

// delay (i.e., wait) for some number of microseconds
extern void               scale_delay_us( int us );
// delay (i.e., wait) for some number of milliseconds
extern void               scale_delay_ms( int ms );

// read Time Stamp Counter (TSC), or "cycle count"
extern scale_tsc_t        scale_tsc();

// read  (or sample) GPIO pin 
extern bool               scale_gpio_rd( scale_gpio_pin_t id         );
// write (or  drive) GPIO pin
extern void               scale_gpio_wr( scale_gpio_pin_t id, bool x );

// check if UART is available for read  (i.e., would doing so block or not)
extern bool               scale_uart_rd_avail();
// check if UART is available for write (i.e., would doing so block or not)
extern bool               scale_uart_wr_avail();
// read  (or  receive) 1-byte from UART
extern uint8_t            scale_uart_rd( scale_uart_mode_t mode            );
// write (or transmit) 1-byte to   UART
extern void               scale_uart_wr( scale_uart_mode_t mode, uint8_t x );

// read  (or  receive) buffer from 7-bit I2C address
extern scale_i2c_status_t scale_i2c_rd( scale_i2c_addr_t addr, uint8_t* x, size_t n );
// write (or transmit) buffer to   7-bit I2C address
extern scale_i2c_status_t scale_i2c_wr( scale_i2c_addr_t addr, uint8_t* x, size_t n );

#endif

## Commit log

2018-11-05 Update UART interface to allow blocking/non-blocking reads and writes; fixed some cases of UART configuration order, plus flush UART after configuration; minor, superficial updates (e.g., wrt. body'l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
    [bsp.h, example.c]
2019-05-15 Revert (i.e., remove) UART flush/drain in initialisation: turns out to be pointless, and annoying!
2019-05-15 Fix bug wrt. UART clock: stems from *main* clk, not *core* (i.e., target) clock, so need to adjust divider accordingly.
2019-05-20 Added some text wrt. issues with Ubuntu-packaged ARM toolchain (i.e., "use ARM release instead")
2019-05-20 Minor update to text wrt. Ubuntu-packaged ARM toolchain
2019-11-14 fix typo. + tweak terminology re. I2C peripherals
2021-11-10 update README re. KiCad URL
2022-04-21 initial attempt at python3 port
    [board.brd, board.csv, board.sch]
2022-07-14 tweak makefile target names for putty (physical+emulated vs. board+emulator)
2022-07-20 switch emulator to python3; allow parameterised emulator host and port
2023-02-27 label warning messages from make for clarity; correct spurious ifndef lpc1114fn28 case
2023-08-25 switch from pycryptodome to pycryptodomex
2023-09-20 force alignment of sections in shared assembly language
2025-09-03 bump pico-python (aka. picoscope) version

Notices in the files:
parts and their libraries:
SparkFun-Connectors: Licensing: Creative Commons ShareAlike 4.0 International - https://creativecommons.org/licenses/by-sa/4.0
